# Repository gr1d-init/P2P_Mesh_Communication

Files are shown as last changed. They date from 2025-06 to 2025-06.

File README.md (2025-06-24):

# P2P_Mesh_Communication_Learning_Kit_SKEE1103_C_Programming_for_Engineers

For this project, our main targeted users were particularly the high school students who are able to comprehend most basic peer-to-peer mesh communication knowledge which often included in STEM subject syllabus such as Computer Science and Physics subject. 

Other than that, students are also exposed to an exciting involvement in Arduino kit development, lies under the usage of microcontrollers, which is a foundational skillset for their Reka Bentuk Teknologi subject that includes hardware and software implementations.

In short, we want student to head the ground up, build up a Peer-to-Peer Mesh Communication Device on their own with given instructions manual, enhance their practical skills on utilise a microcontroller and strengthen their understanding towards wireless communication protocols.

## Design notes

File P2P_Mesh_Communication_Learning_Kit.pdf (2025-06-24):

## ACADEMIC SESSION

2024/2025

# SKEE1103

## C PROGRAMMING FOR ENGINEERS

# GROUP PROJECT

## P2P MESH COMMUNICATION LEARNING KIT

## SECTION 02

## LECTURER: DR. NUR FAIZAL BIN KASRI

# PREPARED BY:

NAME | MATRIC NO.
CHIN YUAN YI | A24KE5081
KOK QI SHENG | A24KE0121
LIM ENG CHIEN | A24KE0138
OOI WEY SHEN | A24KE0270
TONG JIA SHEN | A24KE0313

## Team Description

# TrekAlert

Project Director & Hardware Implementation

Kok Qi Sheng

## “Led the team and constructed the hardware system, ensuring all components were properly assembled and fully functional”

Schematic Drawing & Software Simulation

Lim Eng Chien

## “Created the schematic diagrams and implemented software simulations to verify the design prior to physical assembly”

Assembly & Operational Manual

Chin Yuan Yi
Tong Jia Shen

## “Carried out the hardware assembly process and contributed to writing the instructions manual to ensure proper setup and usage for users”

Documentation

Ooi Wey Shen

## “Conducted research towards the theoretical background and prepared a clear documentation for the report”

## Table of Contents

Section and Title | Page
1.0 Introduction | 1, 2
1.1 Problem Statement | 1
1.2 Objectives | 1
1.3 Scope | 1, 2
2.0 Literature Review | 3, 4
2.1 Overview of Decentralised Mesh Communication Technologies | 3, 4
2.2 Justification for nRF24L01+ Kit | 4
3.0 Methodology | 5, 6
3.1 Problem Formulation | 5
3.2 Hardware and Firmware Design | 5
3.3 Instructional Materials | 6
3.4 Testing and Verification | 6
3.5 Iteration | 6
3.6 Limitations and Future Improvements | 6
4.0 System Overview | 7, 8
4.1 Peer-to-Peer and Mesh Communication Principles | 7, 8
4.2 TrekAlert Working Principle | 8
5.0 Hardware Description, Designs and Implementation | 9 - 18
5.1 Processing Unit: Arduino Nano | 9
5.2 Transceiver Module: nRF24L01+ | 10, 11
5.3 Power Supply | 12
5.4 I/O Device | 13 -15
5.4.1 Push Button Configuration (Microcontroller Input) | 13
5.4.2 LED Configuration (Microcontroller Output) | 14
5.5 Designs and Implementation | 16 - 18
5.5.1 Block Diagram | 16
5.5.2 Fritzing Schematic | 16, 17
5.5.3 KiCad PCB Design and 3D Model Rendering | 17, 18
5.5.4 Final Prototype | 18
6.0 Software Description, Designs and Implementation | 19 - 21
6.1 Feature Overview | 21
7.0 Results and Discussion | 22 - 34
7.1 Assembly Instructions | 22 - 29
7.2 Firmware Installation Instructions | 30 - 32
7.3 Operating Instructions | 33, 34
7.4 Result Showcase | 34
8.0 Future Work | 35
9.0 Conclusion | 36

### 10.0 References

37, 38

1

### 1.0 Appendix

3

9

## 1.0 Introduction

For this project, our main targeted users were particularly the high school students who are able to comprehend most basic peer-to-peer mesh communication knowledge which often included in STEM subject syllabus such as Computer Science and Physics subject.

Other than that, students are also exposed to an exciting involvement in Arduino kit development, lies under the usage of microcontrollers, which is a foundational skillset for their Reka Bentuk Teknologi subject that includes hardware and software implementations.

In short, we want student to head the ground up, build up a Peer-to-Peer Mesh Communication Device on their own with given instructions manual, enhance their practical skills on utilise a microcontroller and strengthen their understanding towards wireless communication protocols.

### 1.1 Problem Statement

In rural or low signal areas such as jungle, mountain trails, maritime or disaster zones, the conventional communication device including mobile phones required cellular network which might no longer available in service.

This presents a huge challenge in terms of team coordination and emergency communication. To address this problem, we introduced the product, TrekAlert, equipped with Peer-to-Peer (P2P) Mesh Communication Technology using Radio Frequency (RF) Wireless Communication Protocol.

RF technology is being targeted to outperform other wireless communication protocols such as WiFi, Bluetooth, Cellular Networks, AM/FM in this specific use case. By utilising this technology as P2P transceiver medium, the nodes can communicate between devices without the aid of cellular network.

### 1.2 Objectives

Develop a hands-on learning kit to demonstrate P2P mesh communication principles
The kit simplifies the concepts of peer-to-peer and mesh communication. This allows students to observe how devices transmit and receive messages across the network without a central hub.

Enable students to design, assemble and program a working device
This kit empowers students to go beyond theory by requiring them to assemble hardware components and getting exposed with firmware that controls the communication nodes. The following will provide them practical experiences with basic microcontroller programming and digital electronic system.

Demonstrate safe, warning and emergency signal propagation without relying on cellular networks
The kit simulates real-world scenarios where conventional communication networks may be unavailable. Students can explore how independent nodes share status updates across the network by sending and receiving predefined signal, in this case, SAFE, WARNING and SOS

### 1.3 Scope

This project focuses on the study of mechanism, design, implementation and demonstration of a peer-to-peer (P2P) mesh communication kit with Arduino Nano and nRF24L01+ module. The scope includes:

- Developing hardware and software that enable basic signal transmission (Safe, Warning, SOS) between multiple nodes.
- Providing hands-on assembly instructions, testing procedures and a ready-to-use educational kit.
- Exploring educational aspects, scale down the conventional devices, allowing students to gain practical experience with microcontrollers and wireless communication

This scope ensures the kit is suitable for classroom and beginner use, while laying the groundwork for future enhancements, such as extended range (LoRa, Zigbee) or graphical displays. For more details, refer future works being discussed in the latter section of the report.

## 2.0 Literature Review

In a real-world application, this kit can be used in various scenarios that lack of cellular network and internet. This includes but not limited to jungle trekking, island explorations and maritime rescue.

Peer-to-peer and mesh wireless communication using LoRa, Zigbee and similar radio technologies has been widely adopted in professional and industry sectors among off-grid applications. For example, military use devices like goTenna Pro X [1] to maintain communication without cellular networks during search and rescue operations. Agricultural sectors also deploy LoRa-based mesh networks, specifically LoRaWAN (Low Power Wide Area Network) [2] for remote sensing and automation, such as monitoring soil moisture and water management across large outdoor areas. For more details, see [3].

Despite these established industrial uses, peer-to-peer mesh radio frequency technology remains niche outside specialized domains. Consumer devices rarely feature these protocols and most personal wireless communication still highly depends on cellular, Wi-Fi, or Bluetooth.

### 2.1 Overview of Decentralised Mesh Communication Technologies

Mesh networking allows devices (which are also known as nodes) to communicate with each other directly or indirectly via intermediate nodes. Meanwhile, data are often encrypted with AES-256 encryption method and routed through secure paths among the mesh topology, hence ensure the data integrity when transferring between nodes, prevent intermediate nodes from accessing other nodes’ message transfer process [4]

Traditional Wi-Fi technology also includes mesh solution, however from a topper view, it still relies on central ISP (Internet Service Provider) thus it is categorised under centralised mesh solution. In this subsection, mainly decentralised mesh solution will be discussed, especially Radio Frequency and Bluetooth. Several decentralised mesh communications technologies have been developed for embedded system and IoT applications:

Figure 1: Node in General Mesh Networking. Adapted from [5]

Protocol | Range & Data Rate | Cost & Complexity | Suitability
Zigbee [6] | Short (~10–100 m), moderate data rate | Expensive modules, requires coordinator, complex setup | Common in home automation; too complex for most beginners
LoRa [7] | Long (~10 km), very low data rate | Expensive, low bandwidth, not real-time | Good for long-range, low updates; unsuitable for responsive projects
BLE Mesh [8] | Short (~10–50 m), moderate data rate | Requires significant memory and setup | Large-scale device comms; too advanced

| | | for simple Arduino projects
nRF24L01+ [9] | Short (~10–100 m), moderate data rate | Very low cost, simple to use, low power | Beginner-friendly P2P; can emulate mesh via custom relay or tree-based routing

Table 2

### 2.2 Justification for nRF24L01+ Kit

After careful consideration and analysis, the Arduino + nRF24L01+ is the most ideal solution for this P2P Mesh Communication Educational Kit due to several reasons:
- Low cost
- Scale down a conventional use case of Radio Frequency Technology, rather than using a Bluetooth technology
- Beginner friendly, enable students’ hands-on interaction on both hardware and software for educational purposes
- Energy efficient, only consumes a low power, suitable for TrekAlert which focus as a pocket tool

## 3.0 Methodology

This section describes the systematic approach taken to design, implement and verify the TrekAlert P2P Mesh Communication Learning Kit as a hands-on learning tool for high school students. The methodology integrates educational learning outcomes with a practical engineering design process to ensure the kit is beginner friendly and low learning curve towards technical aspects.

### 3.1 Problem Formulation

The primary objective is to introduce students to RF wireless peer-to-peer (P2P) decentralised mesh communication, a concept often overlooked in traditional STEM curriculum that focus mostly on Wi-Fi, cellular networks or Bluetooth that most of them rely on the central infrastructure.

Hypothetically, if students can successfully build the kit using provided hardware and instruction manual, able to carry out sending and receive messages across a small RF mesh network, then the kit is an effective educational tool for demonstrating decentralised mesh communication.

Educational goals:
- Develop students’ practical experiences in hardware assembly, microcontroller programming and basic wireless communication protocol
- Strengthen understanding towards RF technology, decentralised P2P mesh communication and logic level manipulation in microcontroller programming
- Encourage and inspire students to excavate the field of communication, contribute to the STEM environment

### 3.2 Hardware and Firmware Design

### 3.2.1 Hardware Design

We selected mainly the low-cost, beginner-friendly components so student can afford them:
- Arduino Nano as control board
- nRF24L01+ transceiver for P2P RF messaging
- LEDs to indicate nodes’ status
- Battery powered for a better portability

### 3.2.2 Firmware Development

Firmware was developed through Arduino code and plugged in with RF24 library that simplifies the wireless messaging between nodes by automating acknowledgement and retransmission process.

Each node carries out a cycle on checking message transmission and reception status, communicate using SAFE/WARNING/SOS states. The firmware source code was well commented and named with proper variables that ensure students can grasp the logic easily and make modifications on top of it for further development. The instruction manual maps the hardware stage to the firmware stage in detail so students can clearly see how each part corresponds to the firmware.

### 3.3 Instructional Materials

A step-by-step instruction for assembling the kit and microcontroller operation mode was well illustrated and discussed, that includes:
- Wiring the components by following the graphical steps, according to the Fritzing schematics
- When assembling the components, understand how active low components were hardware-defined, learn the proper method to setup for different configuration modes
- Installing the firmware source code from GitHub
- Verify and upload firmware to node’s microcontroller chip

### 3.4 Testing and Verification

With two nodes powered on at short range (~15m), students:
- Sent and received predefined messages between the two nodes
- Confirmed successful transceive capability and bidirectional communication
- Verified that communication was achieved without the aid of cellular networks or internet
- Verified nodes’ P2P decentralised mesh communication capability

With the open-source access provided through GitHub, students may always revise the Learning Kit details and modify its usage, carry out further study on theoretical concepts such as radio frequency technology and P2P networks independently.

### 3.5 Iteration

The educators can always visit our project repository, follow the same implementation methodology, they could provide the educational session with their target users, not limited to students only. Researchers or hobbyists can also access the whole project report, to support their own case study or self-guided learning.

### 3.6 Limitations and Future Improvements

While this version only support demonstration for basic two nodes communication, future enhancements may include:
- Adding more nodes to showcase mesh network’s relay capabilities
- Expand to a longer ranged RF network using LoRa technology
- Integrating GUI display for more interactive STEM educational demonstration

For more details on future enhancements, refer 8.0 Future Work section.

## 4.0 System Overview

### 4.1 Peer-to-Peer and Mesh Communication Principles

Each node in the network can function as both a transmitter and a receiver in the independent communication model and that refers to peer-to-peer (P2P) communication. P2P systems improve reliability and autonomy by getting rid with the need for a central infrastructure, in contrast to conventional client-server architectures. In simple word, every node is the central hub itself.

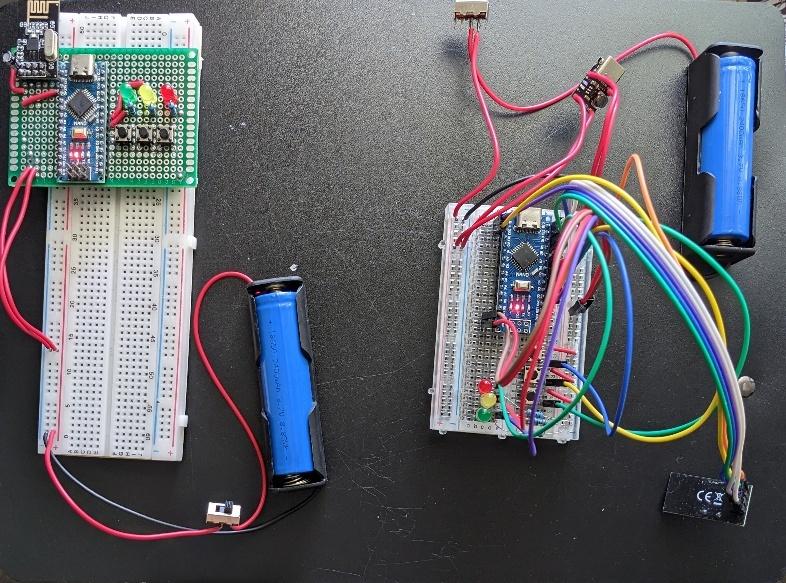
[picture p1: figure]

Figure 2: Two isolated node communication devices

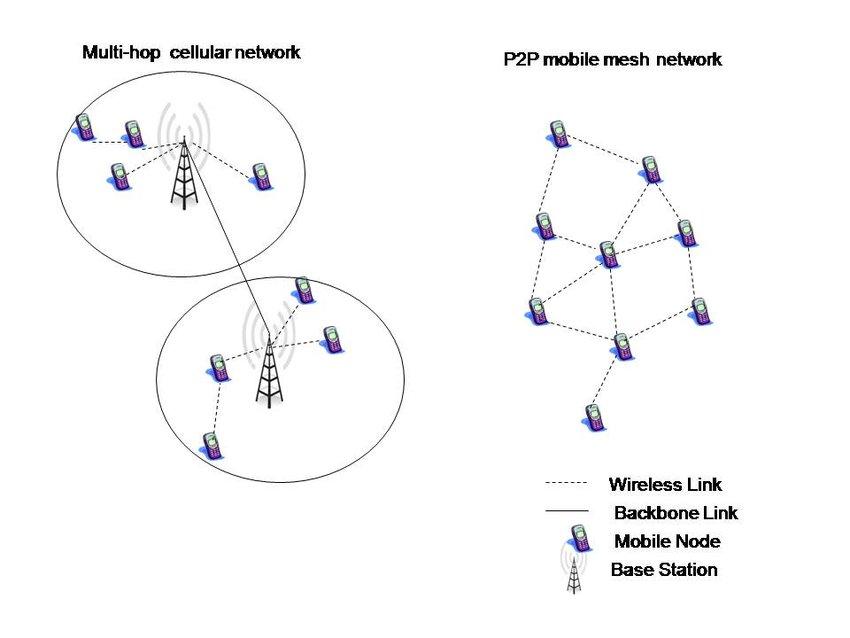
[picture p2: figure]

Figure 3: Comparison between traditional cellular network and P2P decentralised mesh network Adapted from [10]

The P2P idea is extended by mesh communication, which enables several nodes to transmit messages through one another in addition to communicating directly. As a result, data can travel via a variety of routes to reach its destination, forming a decentralised network, enhancing:
- Reliability: Alternative routes can be used if one node fails.
- Scalability: The network can dynamically add new nodes as needed.
- Coverage: Intermediate nodes allow signal coverage to expand wider, act as a signal repeater

Mesh networking can be divided into two categories:
Full Mesh | Partial Mesh (Ad Hoc) [11]

This is the best option, but it requires a lot of work and resources because every node is directly connected to every other node.

This kit uses nodes that connect directly or indirectly, dependent on signal strength or distance. This technology is used by TrekAlert Table 3, Mesh Network Topology, Diagrams adapted from [12]

### 4.2 TrekAlert Working Principle

The TrekAlert Communication System is a portable rechargeable battery-operated Arduino-based device that allows peer-to-peer (P2P) decentralised mesh communication. It enables users to use push buttons to transceive the three predefined status signals—Safe, Warning and SOS from a node to another without cellular network.

The nRF24L01+ module at first node is used to wirelessly broadcast the signals, which are then routed throughout the mesh network and represented on second transceiver nodes by color-coded LEDs. On the other hand, the functionality as transmitter and receiver can be swapped between nodes, allowing a bidirectional communication, which make it outperform the traditional AM/FM transmission and reception.

This kit enables a group of users to communicate basic safety statuses through wireless signal propagation using the nRF24L01+ transceiver module in mesh networks, which every node act as the central device itself.

Each node in the system is an independent device that can carry out three major functions, which are:
- Sending status signals via push button, act as transmitter
- Receiving signals from other nodes, act as receiver
- Communicate with each other bidirectionally through various colours of LEDs with real-time operation, act as transceiver

Three predefined signals can be transmitted by triggering the respective push button through this kit (Table 1):
No. | LED | Message
1 | Green | SAFE (Clear)
2 | Yellow | WARNING (Caution)
3 | Red | SOS (Emergency)
Table 1

## 5.0 Hardware Description, Designs and Implementation

For hardware integration, we have dissected into a few operational parts, mainly:
- Processing Unit
- RF Transceiver
- I/O Device
- Power Supply

### 5.1 Processing Unit: Arduino Nano

The central processing unit (CPU) in each TrekAlert node is the Arduino Nano. It controls push button input detection, RF wireless communication with nRF24l01+ via SPI Protocol and LED signalling. Arduino Nano is best suited for TrekAlert because of its small size, as compared to Arduino UNO, its USB-C programmability, low power consumption and sufficient amount of digital I/O pins makes it an ideal choice for this project.

Figure 4: Arduino Nano. Adapted from [13]

Arduino Nano is based on ATMega328P 8-bit AVR microprocessor. It runs with a clock speed of 16 MHz and operates at a controlled 5 V in this case. Arduino Nano equipped with 14 digital input/output (I/O) pins (D0 – D13) and 8 analog input pins (A0 – A7). It also supports communication between nRF24L01+ module via SPI hardware protocol

Main function of microcontroller in Trek:
- Input Monitoring
Each push button is wired with a pull-up resistor so that the corresponding Nano input pin stays HIGH by default. When a button is pressed, the input pin goes LOW, signalling the microcontroller to begin processing.
- Signal Encoding
When a button is pressed, the Nano encodes a message to SPI protocol, containing:
- The signal type (which button was pressed)
- The node ID (which device is sending)
- A message ID (to help prevent duplicates)
- Data Transmission and Reception
Neighbouring nodes receive the transmitted message through their nRF24L01+ modules over SPI protocol. Each node checks if the message is new, then processes the signal, e.g. triggering a button causes another node to light up an LED.

### 5.2 Transceiver Module: nRF24L01+

The nRF24L01+ is a popular wireless transceiver module that enables communication between microcontrollers. The compact and energy-efficient characteristics, making it easily integrated into educational and embedded projects that required RF wireless communication. Its firmware provided features like automated handshaking and retransmission [14], hence making its setup easier and beginner friendly. Moreover, there are also versions with enhanced antennas available in the market, providing an extended range and stability option for more demanding usages. [15]

Figure 5: nRF24L01+

The following are the key specifications of the nRF24L01+:

Feature | Description
Frequency Band | 2.4 GHz ISM
Data Rate | Up to 2 Mbps
Transmission Range | 50–100 m (open space), varies with environment
Communication Protocol | SPI (Serial Peripheral Interface)
Acknowledgment Support | Auto-ACK and Auto Retransmit
Data Pipes | 6 simultaneous data pipes
Payload Size | Up to 32 bytes per message
External Antenna Option | Available for increased range and reliability
Power Consumption | Very low, ideal for battery-powered devices
Common Applications | Educational kits, embedded systems, P2P or mesh-like networks

Table 4: nRF24L01+ specifications. For more details, see [16].

SPI (Serial Peripheral Interface) and Its Role

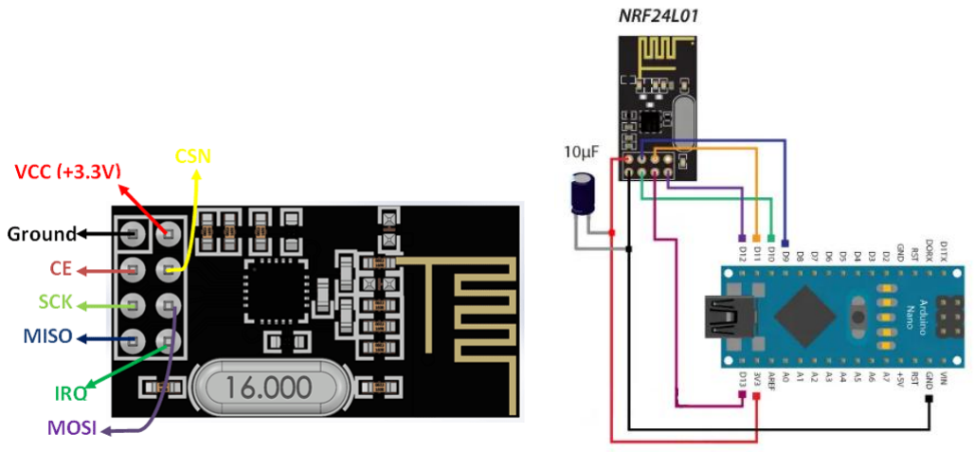
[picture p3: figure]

Figure 6: nRF24L01+ Pinout. Adapted from [9]

The Arduino Nano, a microcontroller act as a Master device and the nRF24L01+ wireless module, a peripheral act as a Slave device can exchange data via the Serial Peripheral Interface (SPI) and it supports the core functionality for TrekAlert, as it is a full-duplex comfmunication protocol.

Pin | Full Name | Direction | Description
MOSI | Master Out, Slave In | Master → Slave | Sends command bytes and data from the microcontroller to the nRF24L01+
MISO | Master In, Slave Out | Slave → Master | Sends data from the nRF24L01+ back to the microcontroller
SCK | Serial Clock | Master → Slave | Synchronizes data transmission
CSN | Chip Select Not | Active Low | Enables (LOW) or disables (HIGH) communication
CE | Chip Enable | Active High | Enables the transceiver to transmit or receive data

Table 5: nRF24L01+ pinout details (SPI Interfrace). Adapted from [17]

### 1. Initialisation

When the system is powered on:
- The Arduino initialises the nRF24L01+ by writing values to its internal configuration registers over SPI.
- This setup includes:
- Payload size
- Transmission power level
- Communication channel (frequency)
- CRC (Cyclic Redundancy Check) error validation and automated acknowledgement

### 2. Transmission

- The Arduino generates the data packet and writes it into the nRF24L01+’s TX FIFO buffer using the SPI protocol.
- The CE (Chip Enable) pin is briefly pulled HIGH to begin transmitting after the data is loaded.
- The signal is subsequently transmitted by the NRF module using 2.4 GHz radio waves.

### 3. Reception

- On the receiving node, the nRF24L01+ listens in RX mode and sets an interrupt flag upon receiving a valid packet.
- The Arduino then reads the data from the RX FIFO buffer using SPI commands.
- After decoding the message, the microcontroller initiates the relevant output action (e.g. turning on the LED to indicate the message).
4. Role of CSN
- The CSN pin is pulled LOW to start SPI communication and HIGH to stop it.
- This guarantees that only one device is active on the SPI bus at a time.

### 5.3 Power Supply

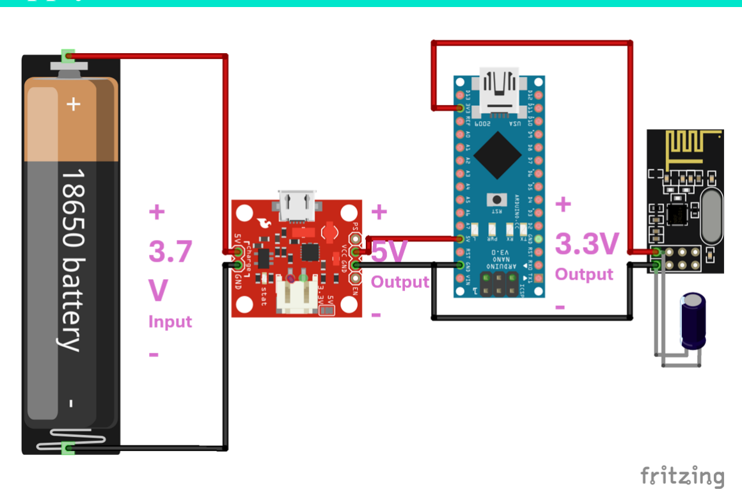
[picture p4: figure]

Figure 7: Power Supply Setup

In our TrekAlert P2P Mesh Communication, we use a charger/booster module to drive the microcontroller and the nRF24L01+ module. Power is supplied by a single 18650 3.7 V Li-ion battery, which is connected into the charger module. The charger module then provides a regulated 5 V output that is fed into the 5V and GND pins of the Arduino Nano.

Meanwhile, the nRF24L01+ module takes its 3.3 V input from the 3V3 output pin on the Arduino Nano. An additional decoupling capacitor is added across the positive and negative terminal to act as a filter, filtering the noise from entering as input.

The charger module also provides a rechargeable solution, allowing battery to be charged without removing it from the enclosure. In off-grid situations such as jungle-trekking, this feature extends the usage time of the device when paired with a power bank, avoid unnecessary battery swaps.

### 5.4 I/O Device

### 5.4.1 Push Button Configuration (Microcontroller Input)

In this project, tactile push buttons are used as the inputs for the user to control the input signals. To ensure a logic level stability when the button is left unpressed, pull-up or pull-down resistors are needed to avoid the floating input.

- Pull-up resistor: Connects the input GPIO pin to Vcc through the resistor. Default state is pulled to HIGH, pressing the button pulls it LOW.
- Pull-down resistor: Connects the input GPIO pin to Ground through the resistor. Default state is pulled LOW, pressing the button pulls it HIGH.
Pull-up resistor | Pull-down resistor

Figure 8: Pull-up and pull-down resistor configurations. Adapted from [18].

Additionally, the resistance value of R1 is crucial for ensuring a stable pull-up or pull-down configuration:

- If R1 is too small, a large current will flow when the switch is closed, resulting an unnecessary power loses. This is known as using a strong pull-up (or pull-down) and less power efficient.
- If R1 is too large, the input may fail to reach a valid logic level when the switch is open due to leakage currents at the microcontroller’s pin. This is referred to as using a weak pull-up (or pull-down).

In TrekAlert, an INTERNAL PULLUP configuration is used to ensure a HIGH logic level by default when button is not pressed. This design results in an active-low configuration, where pressing a button applies a LOW signal to the microcontroller’s input pin. Internal pullup applied the pull-up resistor concept but without the need of adding an external resistor, as built-in microcontroller’s internal pull-up resistor is used.

Configuration wise, common recommendation for external pull-up or pull-down configuration is to select a resistor that is at least 10 times smaller than the impedance of the input pin.

By understanding the principles of circuit behaviour in the circuit, students can understand the voltage divider behaviour. Besides, students can explore logic design and the importance of state management in embedded systems.

### 5.4.2 LED Configuration (Microcontroller Output)

Light-emitting diodes (LEDs) are used in this educational kit as visual indicators for the three statuses, “SAFE, WARNING, SOS”. For a complete tutorial towards LEDs operation, this educational includes the explanation for both active-high and active-low configuration for LEDs. However, the final prototype for this educational kit is equipped with active-low configuration only.

- Active-high: The LED turns ON when the LED’s pin receives a HIGH logic level output by control pin
- Active-low: The LED turns ON when the LED’s pin receives a LOW logic level output by control pin

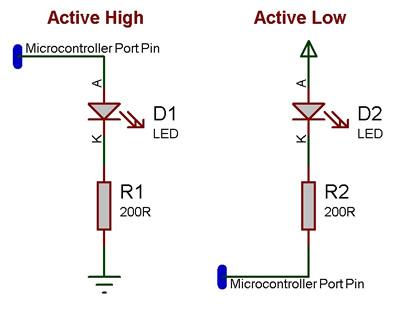
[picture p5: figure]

Figure 9: LEDs’ configuration types. Adapted from [19]

TrekAlert uses an active-low design, meaning that when the microcontroller wants to turn the LED on, it requires GPIO pin to output a LOW signal. In this setup, the cathode of the LED is connected to the microcontroller’s digital output pin through a current-limiting resistor, while the anode is connected to a steady 5 V supply.

When the microcontroller sets its output pin to LOW, it creates a potential difference. This allows current to flow from the 5 V source, through the LED and resistor and into the microcontroller pin. The resulting current flow causes the LED to light up.

In this configuration, the microcontroller is sinking current, which is often more stable and efficient than sourcing current. Thus, the LED illuminates whenever the microcontroller GPIO pin output LOW signal.

The dual-configuration designs of the LED interface enable students to learn:
- How logic levels affect circuit behaviour
- Understand mode of operation of components only defined by hardware
- Reinforce understanding of potential difference, current flow

Signal Flowchart: End-to-End Operation between TrekAlert Node

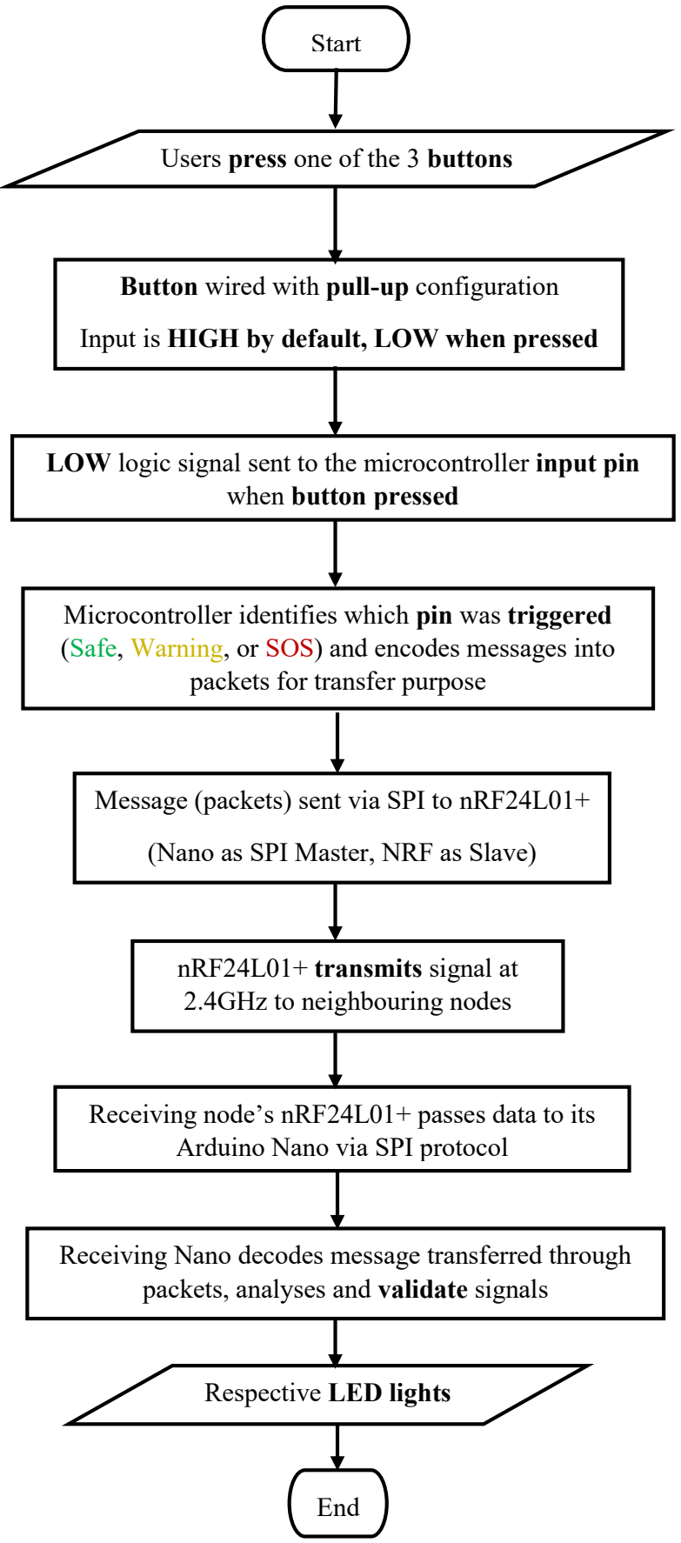
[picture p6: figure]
Start; Button wired with pull-up configuration; when button pressed; packets for transfer purpose; (Nano as SPI Master, NRF as Slave); nRF24L01+ transmits signal at 2.4GHz to neighbouring nodes; Arduino Nano via SPI protocol; packets, analyses and validate signals; Respective LED lights; Users press one of the 3 buttons; End

Input is HIGH by default, LOW when pressed

LOW logic signal sent to the microcontroller input pin

Microcontroller identifies which pin was triggered (Safe, Warning, or SOS) and encodes messages into

Message (packets) sent via SPI to nRF24L01+

Receiving node’s nRF24L01+ passes data to its

Receiving Nano decodes message transferred through

### 5.5 Designs and Implementations

Here comes the section that outlines all the overall system design, circuitry and physical implementation of the TrekAlert project. Several design schematics are provided to illustrate the architecture, interconnections between the components for a final assembly.

### 5.5.1 Block Diagram

Presents a top-level overview of the system, showing the project initiation starting from constructing power supply flow, core components (Arduino Nano, charger module, NRF24L01+) and input/output devices (buttons and LEDs), without the detailed wiring schematics.

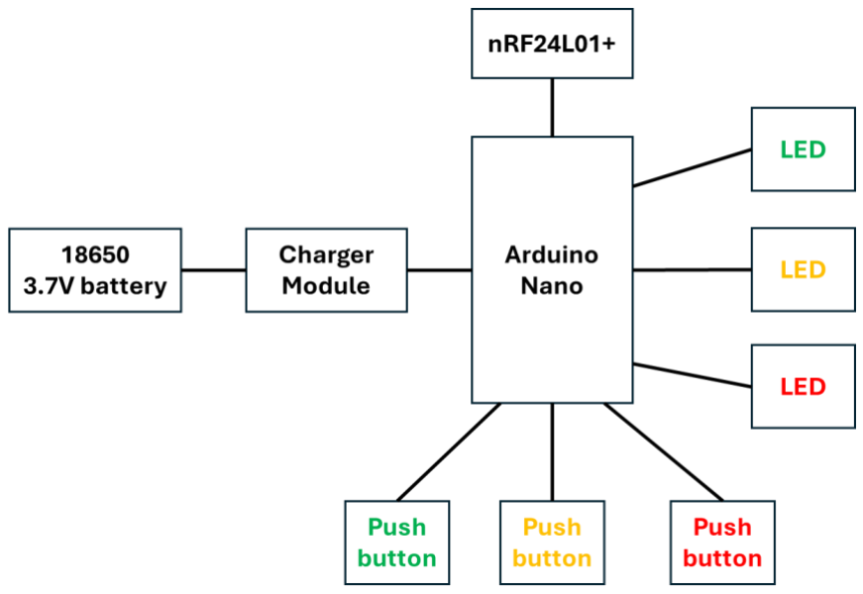
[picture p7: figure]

Figure 10: Block Diagram

### 5.5.2 Fritzing Schematic

Presents a circuit-level wiring of all components on a breadboard, as well as detailed wiring schematics, upgraded from block diagram.

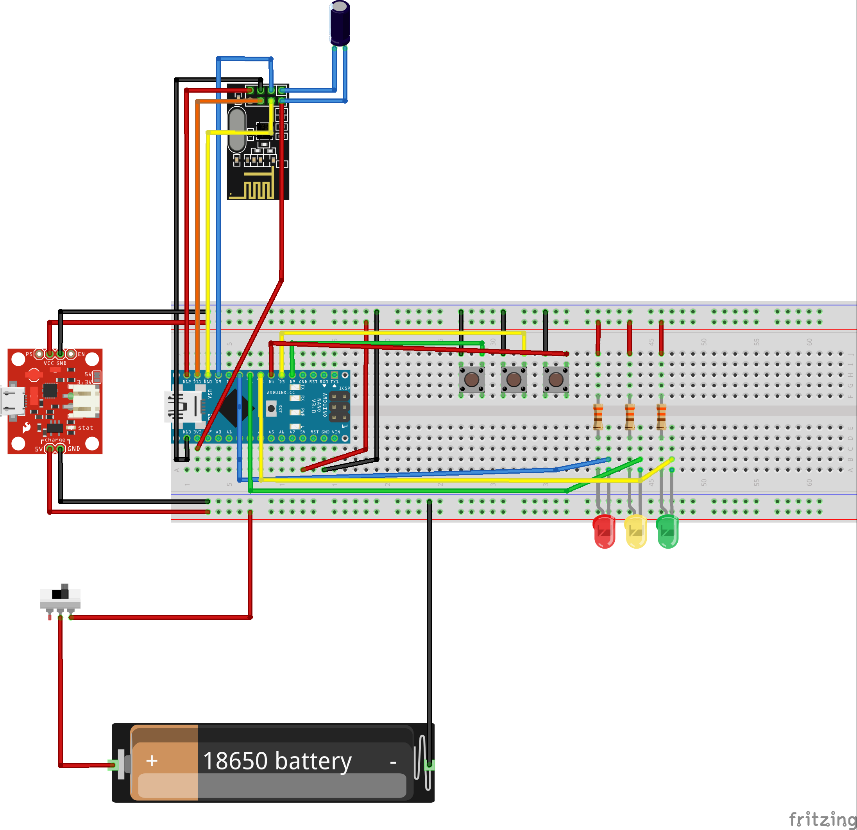
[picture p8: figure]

Figure 11: Breadboard Schematic

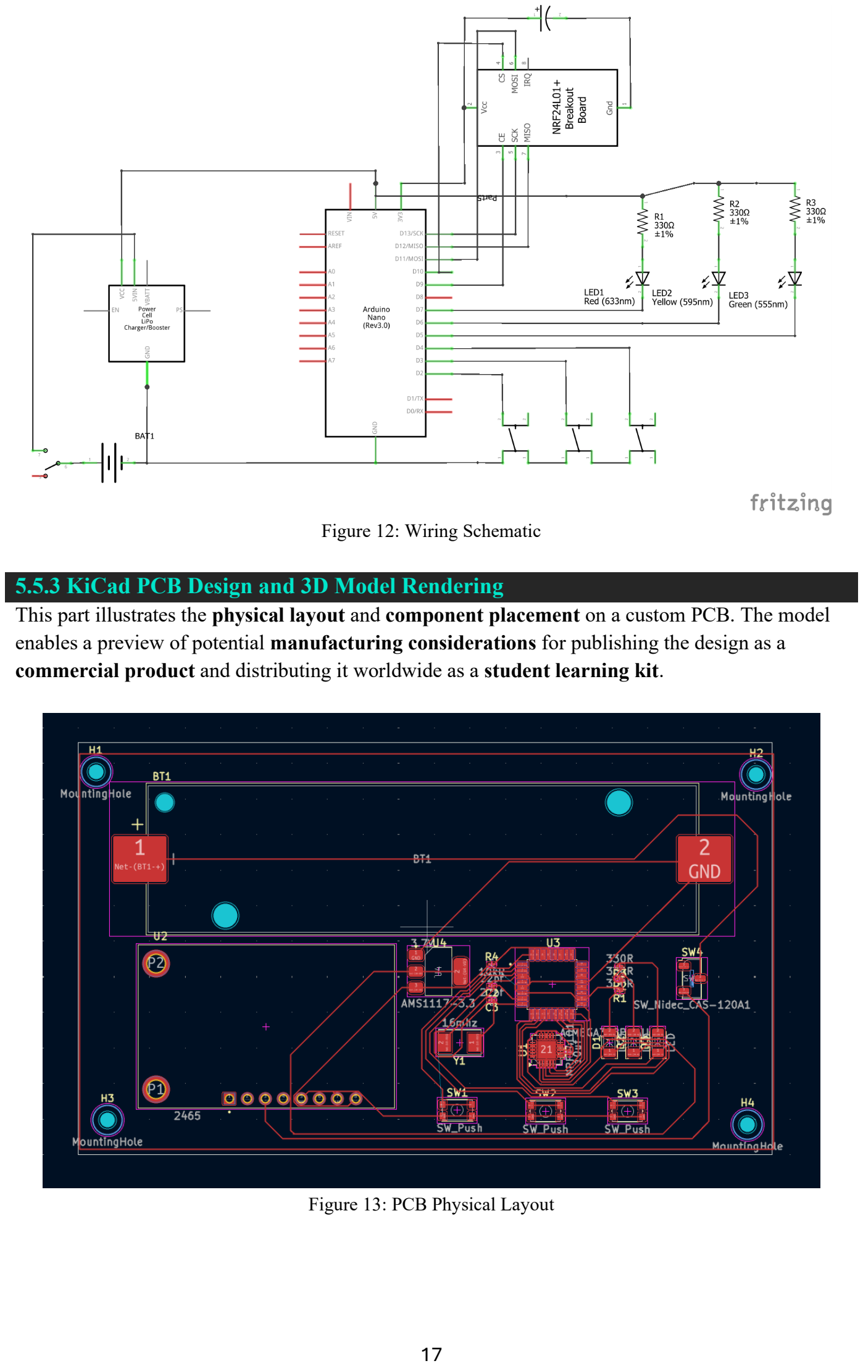
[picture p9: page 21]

Figure 12: Wiring Schematic

### 5.5.3 KiCad PCB Design and 3D Model Rendering

This part illustrates the physical layout and component placement on a custom PCB. The model enables a preview of potential manufacturing considerations for publishing the design as a commercial product and distributing it worldwide as a student learning kit.

Figure 13: PCB Physical Layout

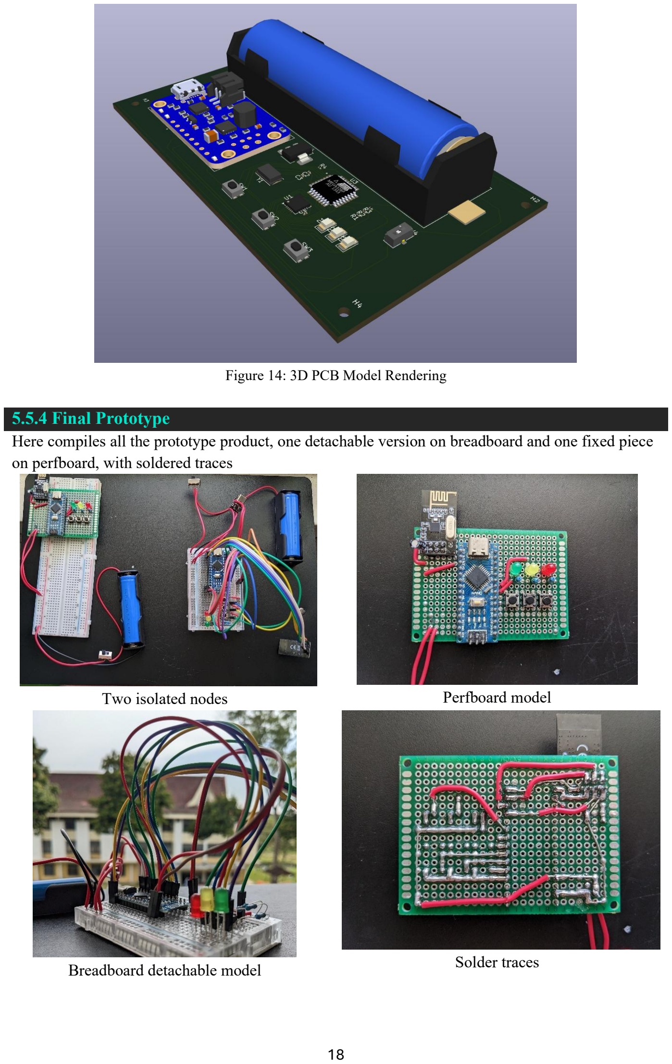
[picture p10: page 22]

Figure 14: 3D PCB Model Rendering

### 5.5.4 Final Prototype

Here compiles all the prototype product, one detachable version on breadboard and one fixed piece on perfboard, with soldered traces

Two isolated nodes | Perfboard model
Breadboard detachable model | Solder traces

## 6.0 Software Description, Designs and Implementations

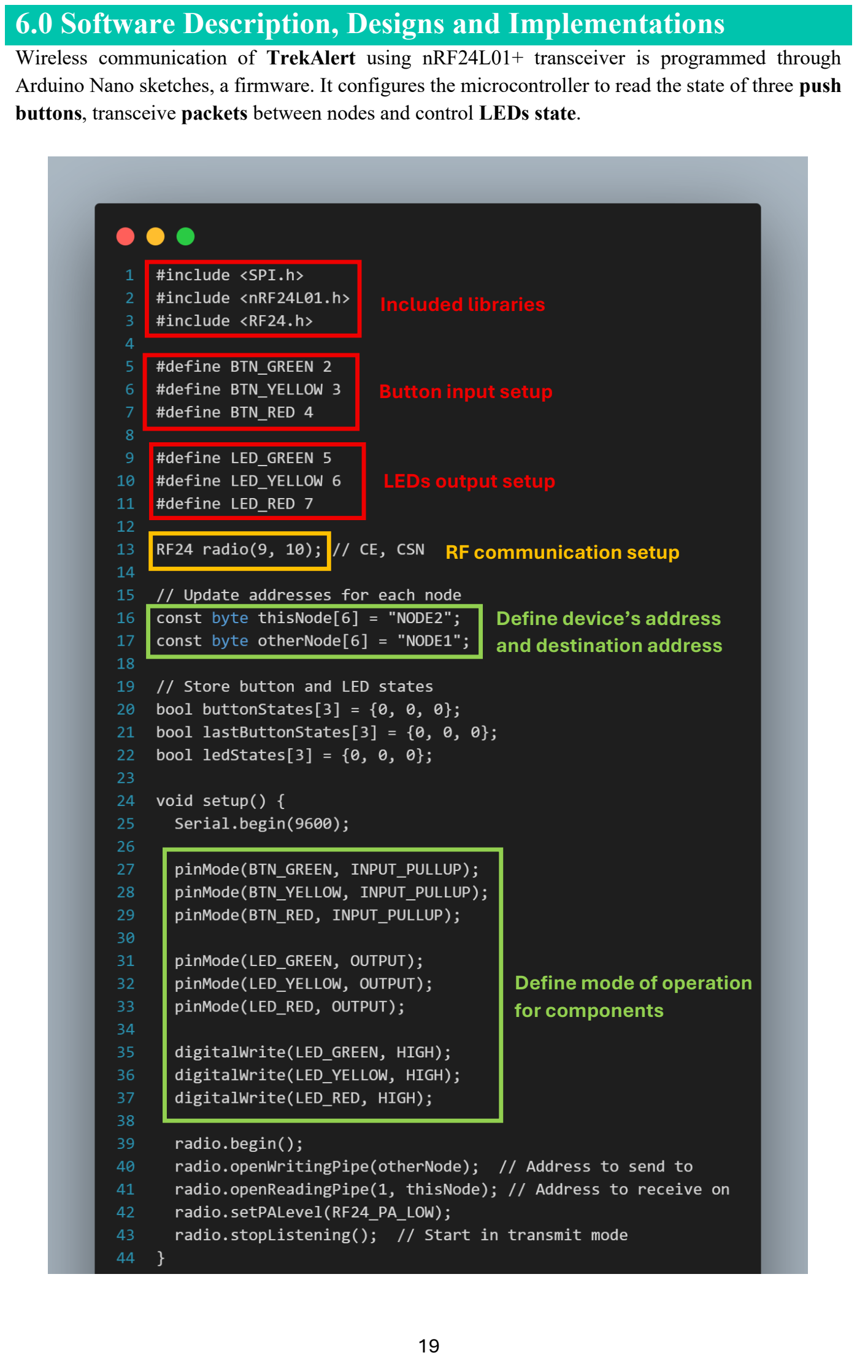
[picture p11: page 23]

Wireless communication of TrekAlert using nRF24L01+ transceiver is programmed through Arduino Nano sketches, a firmware. It configures the microcontroller to read the state of three push buttons, transceive packets between nodes and control LEDs state.

## Included libraries

## Button input setup

## LEDs output setup

## RF communication setup

## Define device’s address and destination address

## Define mode of operation for components

Main loop() logic:
1. Reads the buttons (active-low) and updates the buttonStates
2. Compares current state vs. last state — if any button changed, prepares data to send
3. Uses radio.stopListening(), change to transmit mode, then radio.write() to send updated buttonStates
4. Switches back to receive mode (radio.startListening()), waits for data for up to 5 ms
5. If data is received (radio.available()), updates the LED states

This mechanism flows indicates a construction of transceiver mode for each node. It continuously performs checking and switching between transmitter and receiver modes to ensure the transceiver mode go smoothly.

### 6.1 Feature Highlights

- Edge-triggered Transmission — Only sends new data when a button state changes
- Active-low Input Logic — Uses pull-ups so unpressed buttons read HIGH
- Wireless Duplex — Operates as both transmitter and receiver on the same device with a 5ms checking intervals
- Power Efficiency — Low-power mode for the nRF24L01+ (setPALevel(RF24_PA_LOW))

This firmware integrates hardware inputs (buttons) and outputs (LEDs) with radio communication. Each node continuously monitors its own inputs and broadcasts any changes. It also listens for incoming packets to control its LEDs according to the states sent by its peer.

## 7.0 Results and Discussion

We packaged this P2P Mesh Communication system as a discrete components kit for educational purposes, allowing students to build their own communication device from the ground up.

To support this hands-on learning experience, we have published a detailed instruction manual that includes step-by-step assembly guidelines and demonstrations of its operation.
The demonstration verified that:
- Transceiving process successfully carried out between nodes
- LEDs light up as expected
- System works at certain range

When the user receives this educational kit, there will be 2 modules, one is the perfboard module and the another is a breadboard module, for educational purpose, user will be required to assemble the breadboard module themselves.

Throughout the instructions manual below, students will be able to comprehend the basic mechanism of the device as per discussed

### 7.1 Assembly Instructions

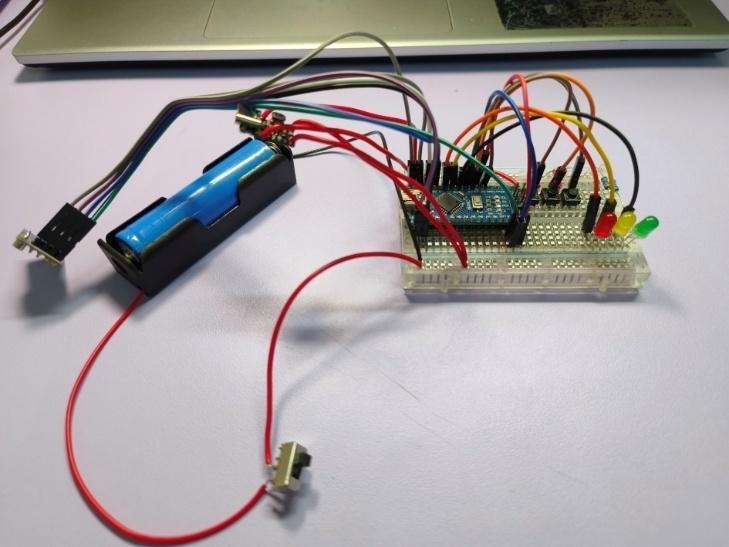
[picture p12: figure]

This Arduino breadboard circuit is a jungle trekking peer-to-peer mesh communication system. By using an nRF24L01+ module, it allows communication between two jungle trekking peer-to-peer devices. Both devices are allowed to send and receive data and trigger the LED on the opposite device, giving simple warnings or alerts to your partner during jungle trekking. It is a great beginner project for students to assemble the device from scratch and learn Arduino with the following components.

Components required

Components | Quantity
Breadboard | 1
Arduino nano board | 1
nRF24L01+ | 1
Charger module | 1
330Ω resistor | 3
Red LED | 1
Yellow LED | 1
Green LED | 1
Push button | 3
Slide switch | 1
3.7V battery | 1
Battery holder | 1
Jumper wires (male to male) | 8
Jumper wires (male to female) | 7

Step 1: Arduino nano
- Place the Arduino nano at the breadboard as show in figure above

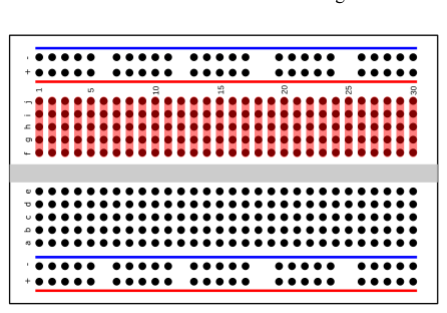
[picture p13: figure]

- The figure above shows the connection in a breadboard
- In the main area, there are 5 holes in each vertical row that are electrically connected. (e.g. a,b,c,d,e holes are connected vertically)
- Horizontal connection in the power rails to connect power and ground across the length of the power rail
- The central gap to keeps the two halves of the main area separated

Step 2: Battery

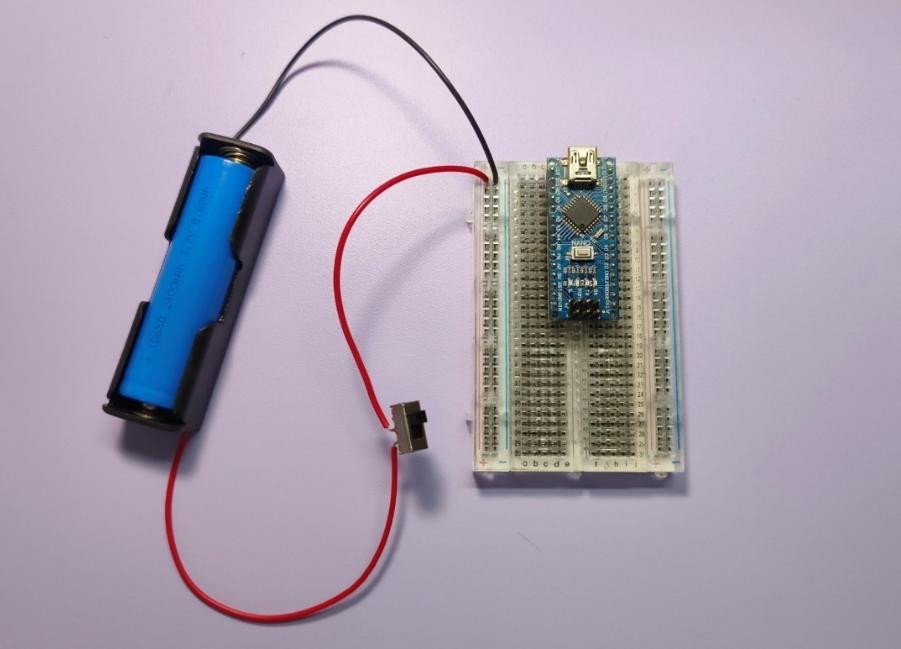
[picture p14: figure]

- Connect the battery to the breadboard as shown in figure above to match with the sign on the breadboard
- Connect the red wire (positive terminal) of the battery holder to breadboard power rail marked ‘+’
- Connect the black wire (negative terminal) of the battery holder to breadboard power rail marked ‘-’
Step 3: Connecting to charger module

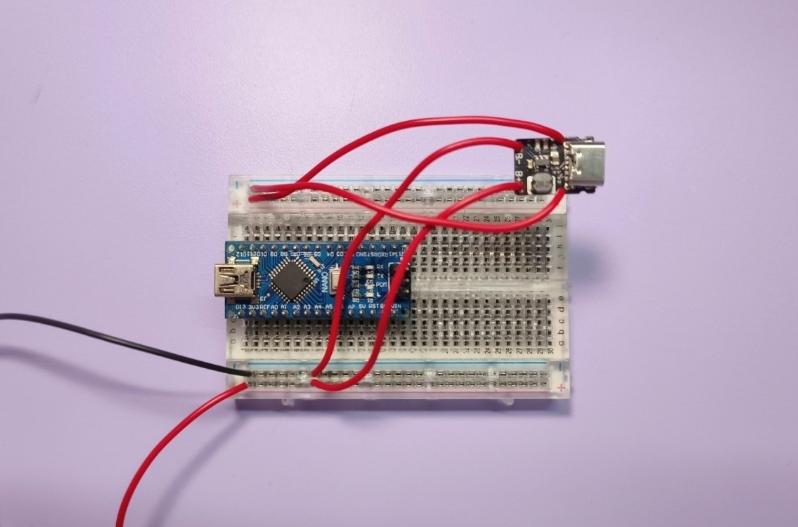
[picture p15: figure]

- The charger module functions as a boost converter, by stepping up 3.7V from the battery to 5.0V, to powering the Arduino nano since it requires 5V input voltage.
- It is also used to charge up the battery with type-c port
- Connect the Charger module to the breadboard as above

- Connect the B+ pin of the charger module to the left + power rail (where the positive terminal of the battery holder is connected)
- Connect the B- pin of the charger module to the left - power rail (where the negative terminal of the battery holder is connected).
•
- Connect the + output pin of the charger module to the right + power rail."
- Connect the - output pin of the charger module to the right - power rail
Step 4: Connect the push button
- The configuration of push button used is active low configuration, meaning the input pin will read low when the button is pressed.
- This setup assume that Arduino nano internal pull-up resistor is used on the input pin.
- Place one push button onto the breadboard, as shown in the figure above
- Connect one terminal of push button to Arduino nano Pin D2
- Connect the other terminal of push button to power rail GND

Repeat this step by connecting 2 more push button

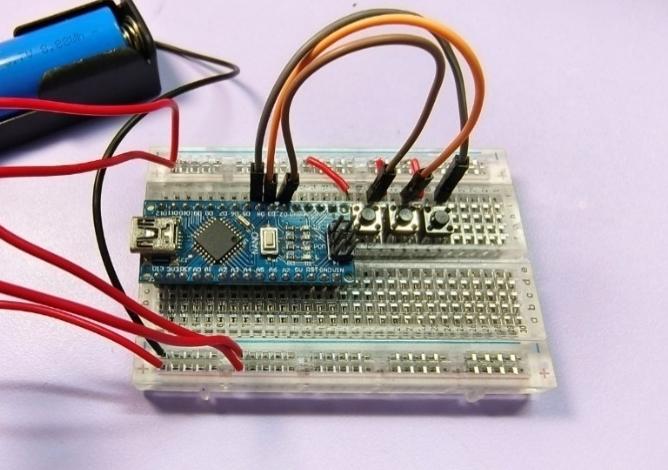
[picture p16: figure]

- Place the push buttons as the setup shown above
- Connecting one terminal of the push button to input pins (D3 and D4) and the other end to GND rail

Step 5: Connecting the LEDs

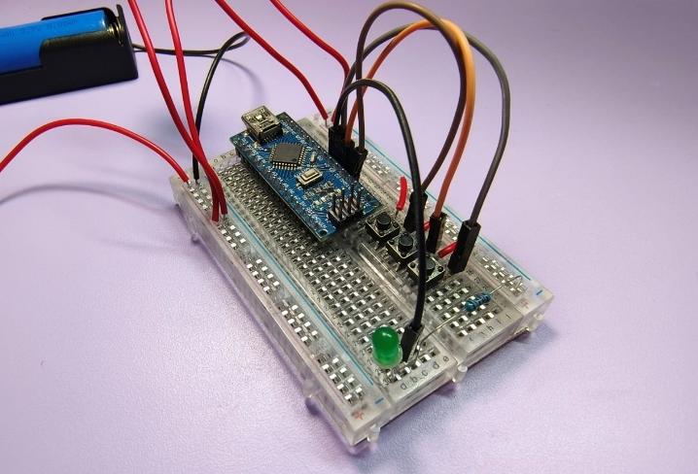
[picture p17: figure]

- The LED is connected in active low configuration
- LED will illuminate when its corresponding GPIO pin (D5,D6,D7) is set to low (0V)
- NOTE: The longer leg of an LED is the anode(+), while the shorter leg of an LED is cathode (-)
- Connect one end of the 330Ω resistor to ‘+’ 5V power rail
- Connect the other end of 330Ω resistor to anode (positive leg) of the LED
- Connect the cathode (negative leg) of LED to the GPIO pin (D7,D6,D5)
- Repeat these steps for the remaining two LEDs (yellow and green), connecting each to a separate GPIO pin (Red to D7, Yellow to D6, Green to D5) as illustrated in the diagram below

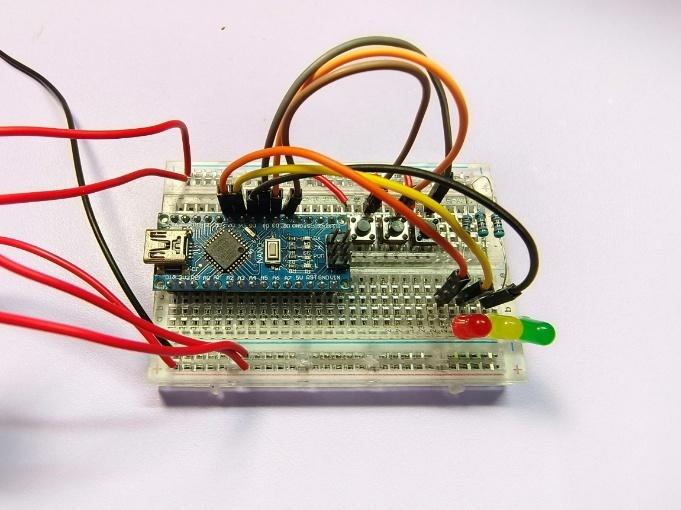
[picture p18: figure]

Step 6: nRF24L01+ module

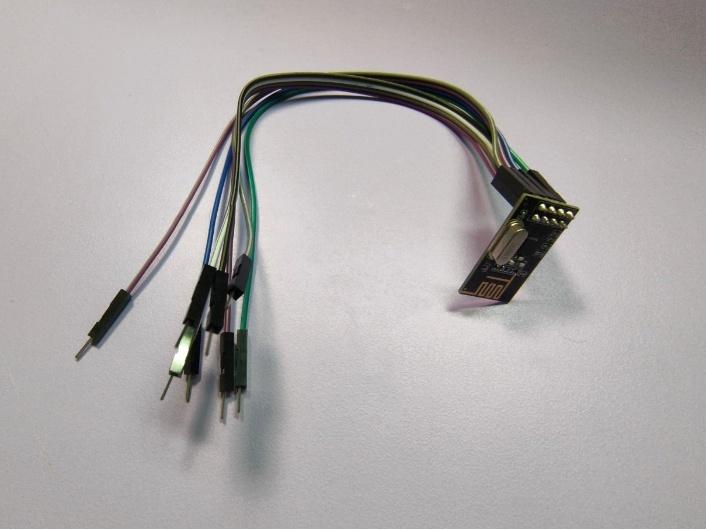
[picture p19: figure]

- Use male to female jumper wire to connect the nRF module to Arduino
- The pinout diagram of nRF module is as below

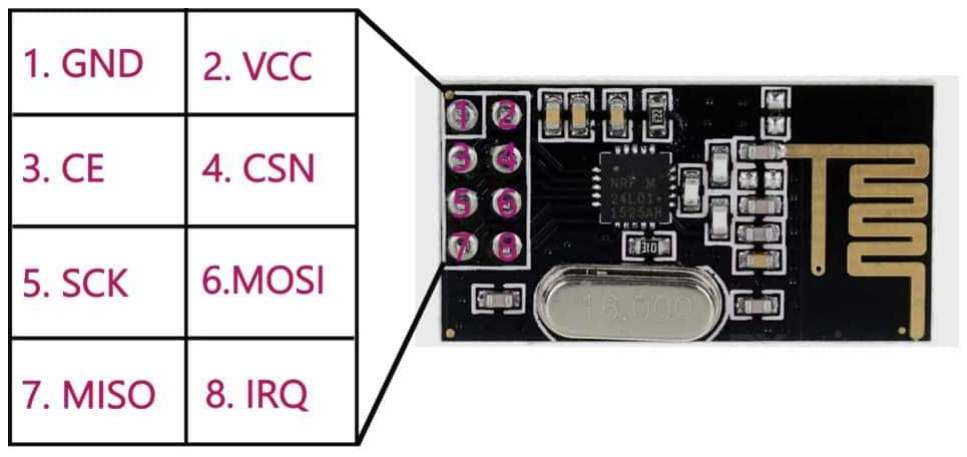
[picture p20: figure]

nRF24L01+ pin | Arduino nano pin
GND | Power rail GND
VCC | Power rail 3.3V (Do not connect to 5V)
CE | D9
CSN | D10
SCK | D13
MOSI | D11
MISO | D12
IRQ | Not used

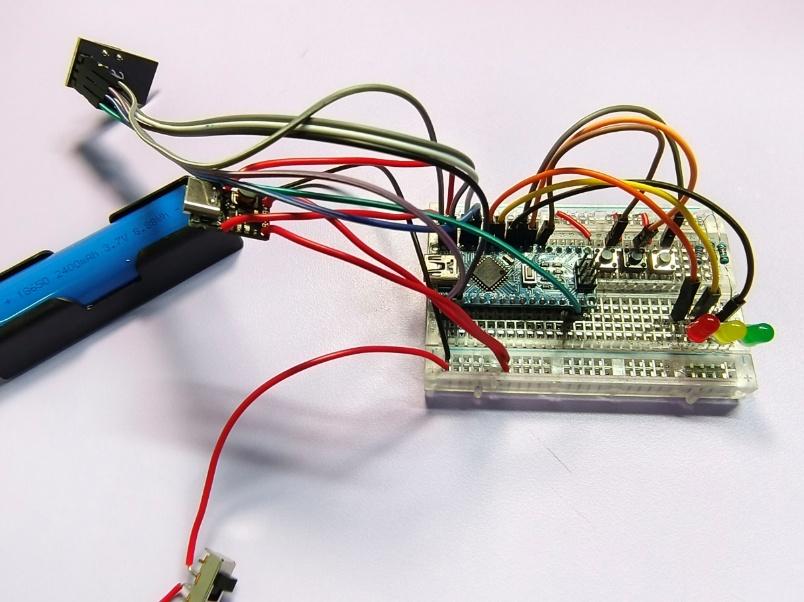
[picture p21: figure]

Step 7: VCC and GND

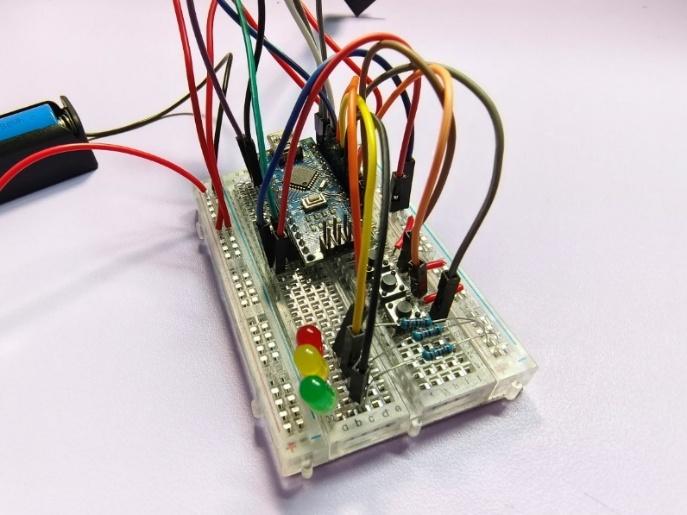
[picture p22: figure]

- Supply power to the Arduino nano from the breadboard regulated 5V and GND power rail
- Connect the Vin pin on the Arduino nano to the ‘+’ (5V) power rail.
- Connect the GND pin on the Arduino nano to the ‘-’ (GND) power rail.

Final product of a single P2P mesh communication node on breadboard

## 7.2 Firmware Installation Instructions

### Step 1: Connect Arduino and PC using cable

Insert the cable type C side to Arduino and USB A side to PC

### Step 2: Configure Arduino Firmware Through Sketches

1) Import Code

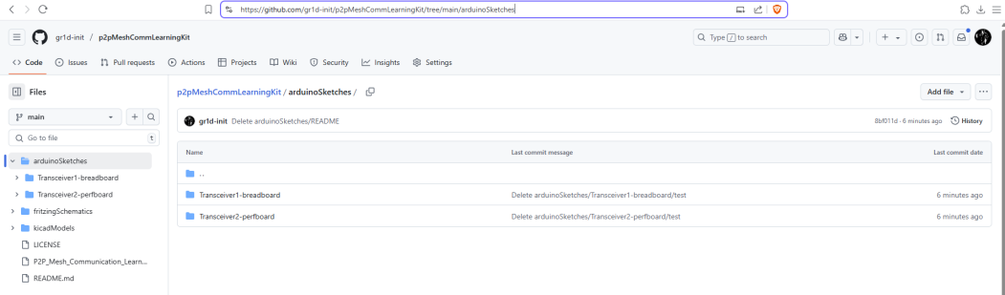
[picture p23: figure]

This project is published to the open-source community on GitHub,
hence students are only required to obtain the firmware from the link below https://github.com/gr1d-init/p2pMeshCommLearningKit/tree/main/arduinoSketches follow the to install the source code, unzip the file and you will get source code file named Transceiver1-breadboard.ino, open it using Arduino IDE
2) Connect Arduino to PC and Initializing

Connect Arduino to your PC using the cable provided, at the top right select the USB port NOTE: If occur more than 1 unknown usb devices, make sure to remove other USB devices on your computer and indicate the USB port name of your Arduino (In this case Arduino are connected to COM6 port)

Now, select Arduino Nano as the board and select the proper port. Click OK to save.

### Step 3: Declaring Coding based on Arduino I/O Pins

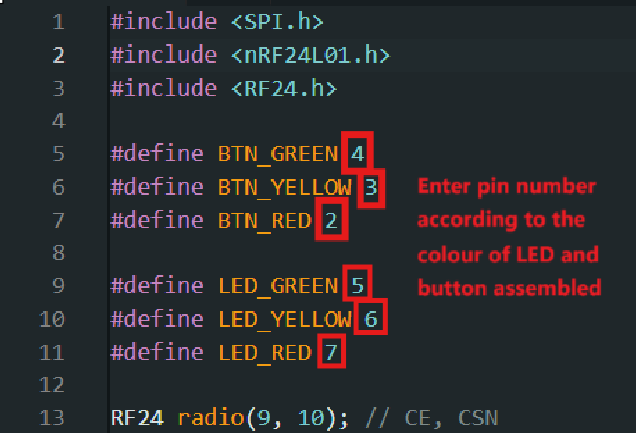
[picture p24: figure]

Now we are focusing on the coding.
From line 5 to line 11, declare the Arduino pin number according to the button and LED assembled.

In this case :

D2 → Blue Jumper → BTN_RED
D3 → Yellow Jumper → BTN_YELLOW D4 → Brown Jumper → BTN_GREEN D5 → Purple Jumper → LED_GREEN D6 → Red Jumper → LED_YELLOW
D7 → Green Jumper → LED_RED

From line 13, declare the Arduino pins according to NRF module.

In this case :
D9 → Green Jumper → CE
D10 → Blue Jumper → CSN

### Step 4: Verify and Upload to Arduino

After done all the declaration, what we need is to burn the firmware into Arduino. The first step is clicking the √ button to verify, waiting IDE to done compiling. Next, click → button to upload the firmware.

Please wait patiently and DO NOT disconnect the Arduino from your PC while uploading.

At the end, you are successfully burned in the firmware once the Done Uploading message pop up.

## 7.3 Operating Instructions

### Step 1: Turn on Power Supply

Push the button
to ON 1

The power indicator
light will turn on

indicate Arduino are 2 in working mode

The blue light will turn on indicate power booster module 3 are in working mode

### Step 2: Button Mode

Situation : When necessary to communicate with another teammate, push the button according to colour assigned

Green button on module 1
pressed, green light on 1 module 2 light up

Yellow button on
module 1 pressed,

yellow light on 2 module 2 light up

Red button on module 1
pressed, red light on 3 module 2 light up

## 7.4 Result Showcase

In our demonstration video, we carried out some testing and verification:

- Tested switching in active-low with internal pull-up configuration
- Verified LED logic (in active-low configuration)
- Sent and received predefined signals between the two nodes
- Confirmed successful transceive capability and bidirectional communication
- Verified that communication was achieved without the aid of cellular networks or

internet

- Verified nodes’ P2P decentralised mesh communication capability

Follow the link to see the demonstration video: https://youtu.be/UirkyzqIXWE

## 8.0 Future works

Challenges
- The current setup only demonstrated direct communication between two nodes
- The repeater feature of the peer-to-peer mesh (Node 3 as a relay) was not fully utilised

in this version

- Given the short range of the nRF24L01+ modules, the system may face limited operational

distance in larger or more complex terrains

- The demonstration focused only on using LEDs to show communication status. However,

the hardware can support much more, it is capable of any signal processing task, unlike

traditional walkie-talkies that only transmit audio

- Security issue due to absence of encryption among the intermediate node’s communication

Improvements
- Implement a third node to fully demonstrate and test the repeater functionality for

extending the network range

- For larger-scale or long-distance communication, consider using alternative radio

technologies such as LoRa to achieve better range and scalability

- Expand the user interface by integrating a graphical OLED panel or even a computer

device, allowing the system to display messages and other data beyond simple LEDs,

implement a feature-rich device that support SMS, document transfers

- Develop a waterproof enclosure for the node to ensure it can operate reliably in harsh

outdoor conditions, especially in rainy or humid environments

- Implement AES-256 encryption for transmitted signals to enhance privacy and security,

ensuring that only authorised devices can read or process the messages, prevent intermediate

nodes from intercepting the message

## 9.0 Conclusion

Our project focused on two primary objectives:

- Exposing students to peer-to-peer (P2P) mesh communication
- Providing hands-on experience in learning to program a microcontroller under their RBT, Computer Science and Physics syllabus

With the aid of our learning kit, students can gain foundational knowledges in assembling hardware, developing firmware and implementing wireless communication between devices. This hands-on approach equips them with a deeper understanding of embedded systems, encourages problem-solving skills, synchronise with their Computer Science and Physics syllabus and benefits for further exploration in the fields of electronics and communication engineering as well.

As time evolve, P2P Decentralised Mesh Communication Technology with RF wireless communication protocol has become a rising technology that increasingly come into our sight. It remains a great potential in the domestic sectors, which currently only being implemented among professional and industry usages, such as military and agriculture. Thus, a domestic market of among this technology is still waited to be explored and excavated. For more details, see [20], [21], [22], [23], [24].

In short, we hope more students get exposed to this technology and head the grounds up, build and construct a P2P Mesh Communication node on their own with provided manuals. As STEM workers are highly in demand these days, we sincerely hope students who get accessed to this kit getting inspired and start contributing their efforts and research on this P2P Mesh Communication Topic to enhance networking technology.

Last but not least, we are driven to deliver the very best in our P2P Mesh Communication Learning Kit to capture the true essence of an educational kit.

## 10.0 References

[1] goTenna. “goTenna and Everywhere Communications Form Strategic Partnership Transforming Enhanced Connectivity,” goTenna Newsroom. Accessed: May 28, 2025. [Online]. Available: https://gotenna.com/blogs/newsroom/gotenna-and-everywhere-communications-form-strategic-partnership-transforming-enhanced-connectivity. (https://gotenna.com/blogs/newsroom/gotenna-and-everywhere-communications-form-strategic-partnership-transforming-enhanced-connectivity)
[2] LoRa Alliance. “LoRaWAN for Smart Agriculture,” LoRa Alliance Video. (Aug 11, 2023). Accessed: May 29, 2025. [Online Video]. Available: https://youtu.be/l2m9ZJIEZ0g?si=08_inty-NZJ2JIVr. (https://youtu.be/l2m9ZJIEZ0g?si=08_inty-NZJ2JIVr)
[3] LoRa Alliance. “LoRaWAN® for Smart Industry,” LoRa Alliance Industry Vertical Market. Accessed: May 29, 2025. [Online]. Available: https://lora-alliance.org/industry-vertical-market/.
[4] Zenarmor. “Mesh Topology: Definition, Practices and Importance,” Zenarmor Docs. Accessed: Jun. 1, 2025. [Online]. Available: https://www.zenarmor.com/docs/network-basics/what-is-mesh-topology. (https://www.zenarmor.com/docs/network-basics/what-is-mesh-topology)
[5] BBC Bitesize. “Computer Networks and Topologies – Mesh networks,” BBC Bitesize. Accessed: Jun. 1, 2025. [Online]. Available: https://www.bbc.co.uk/bitesize/guides/z7mxh39/revision/6.
[6] YouTube. “What is Zigbee and How it Works | Zigbee Network Explained,” (May 22, 2021).
Accessed: Jun. 2, 2025. [Online Video]. Available: https://youtu.be/pFDkibWy0yg?si=w_VuCWbKM7w4yXwP.
[7] CDEBYTE. “News,” CDEBYTE. Accessed: Jun. 2, 2025. [Online]. Available: https://www.cdebyte.com/news/587.
[8] Wikipedia. “Bluetooth Mesh Networking,” Wikipedia. Accessed: Jun. 3, 2025. [Online]. Available: https://en.wikipedia.org/wiki/Bluetooth_mesh_networking.
[9] HowToMechatronics. “Arduino Wireless Communication with NRF24L01 Tutorial,” HowToMechatronics. Accessed: Jun. 5, 2025. [Online]. Available: https://howtomechatronics.com/tutorials/arduino/arduino-wireless-communication-nrf24l01-tutorial/. (https://howtomechatronics.com/tutorials/arduino/arduino-wireless-communication-nrf24l01-tutorial/)
[10] ResearchGate. “Multi-hop cellular network and P2P mobile mesh network,” ResearchGate. Accessed: Jun. 7, 2025. [Online]. Available: https://www.researchgate.net/figure/Multi-hop-cellular-network-and-P2P-mobile-mesh-network_fig1_46476397. (https://www.researchgate.net/figure/Multi-hop-cellular-network-and-P2P-mobile-mesh-network_fig1_46476397)
[11] GeeksforGeeks. “Introduction of Mobile Ad-hoc Network (MANET),” GeeksforGeeks. Accessed: Jun. 7, 2025. [Online]. Available: https://www.geeksforgeeks.org/computer-networks/introduction-of-mobile-ad-hoc-network-manet/. (https://www.geeksforgeeks.org/computer-networks/introduction-of-mobile-ad-hoc-network-manet/)
[12] TechTarget. “Definition of Mesh Network Topology,” IoT Agenda. Accessed: Jun. 10, 2025. [Online]. Available: https://www.techtarget.com/iotagenda/definition/mesh-network-topology-mesh-network. (https://www.techtarget.com/iotagenda/definition/mesh-network-topology-mesh-network)

[13] Arduino Store. “Arduino Nano,” Arduino Official Store. Accessed: Jun. 14, 2025. [Online]. Available: https://store.arduino.cc/products/arduino-nano.
[14] NRF24 Library Docs. “RF24 Class Reference,” NRF24 GitHub Pages. Accessed: Jun. 15, 2025. [Online]. Available: https://nrf24.github.io/RF24/classRF24.html.
[15] Cytron Technologies. “Wireless NRF24L01 Plus PA/LNA with Antenna,” Cytron. Accessed: Jun. 15, 2025. [Online]. Available: https://my.cytron.io/p-wireless-nrf24l01-plus-pa-lna-with-antenna. (https://my.cytron.io/p-wireless-nrf24l01-plus-pa-lna-with-antenna)
[16] SparkFun. “nRF24L01+ Product Specification,” SparkFun. Accessed: Jun. 17, 2025. [Online]. Available: https://cdn.sparkfun.com/assets/3/d/8/5/1/nRF24L01P_Product_Specification_1_0.pdf.
[17] Last Minute Engineers. “nRF24L01+ Arduino Wireless Communication,” Last Minute Engineers. Accessed: Jun. 18, 2025. [Online]. Available: https://lastminuteengineers.com/nrf24l01-arduino-wireless-communication/. (https://lastminuteengineers.com/nrf24l01-arduino-wireless-communication/)
[18] Circuits-DIY. “Pull-up and Pull-down Resistor Electronics Tutorial,” Circuits-DIY. Accessed: Jun. 22, 2025. [Online]. Available: https://www.circuits-diy.com/pull-up-and-pull-down-resistor-electronics-tutorial/. (https://www.circuits-diy.com/pull-up-and-pull-down-resistor-electronics-tutorial/)
[19] Flowcode. “Component: LED Array Template,” Flowcode Wiki. Accessed: Jun. 22, 2025. [Online]. Available:
https://www.flowcode.co.uk/wiki_old/wikiv8/index.php?title=Component:_LED_Array_Template_(Outputs:_LEDs). (https://www.flowcode.co.uk/wiki_old/wikiv8/index.php)
[20] Chai, Y., Zeng, X.-J., & Liu, Z. “The future of wireless mesh network in next-generation communication: a perspective overview,” Evolving Systems, Apr. 28, 2025 (e-pub ahead of print, Aug. 2024). Accessed: Jun. 24, 2025. [Online]. Available: https://www.researchgate.net/publication/380031685_The_future_of_wireless_mesh_network_in_next-generation_communication_a_perspective_overview (https://www.researchgate.net/publication/380031685_The_future_of_wireless_mesh_network_in_next-generation_communication_a_perspective_overview)
[21] Berto, R.; Napoletano, P.; Savi, M. “A LoRa-Based Mesh Network for Peer-to-Peer Long-Range Communication,” Sensors, vol. 21, no. 13, p. 4314, Jun. 24 2021. Accessed: Jun. 24, 2025. [Online]. Available: https://doi.org/10.3390/s21134314
[22] Roots Analysis. “Wireless Mesh Network Market, Till 2035,” Roots Analysis, published recently. Accessed: Jun. 24, 2025. [Online]. Available: https://www.rootsanalysis.com/wireless-mesh-network-market (https://www.rootsanalysis.com/wireless-mesh-network-market)
[23] MDPI. “Performance Evaluation of a Mesh-Topology LoRa Network,” May 2025. Accessed: Jun. 24, 2025. [Online]. Available: https://www.mdpi.com/1424-8220/25/5/1602
[24] Wikipedia. “Meshtastic,” updated Jun. 2025. Accessed: Jun. 24, 2025. [Online]. Available: https://en.wikipedia.org/wiki/Meshtastic

## 11.0 Appendix

KSSM Form 4 Physics — Relevance to Types of Waves

KSSM Form 2 Reka Bentuk dan Teknologi — Relevance to Microcontroller Usage

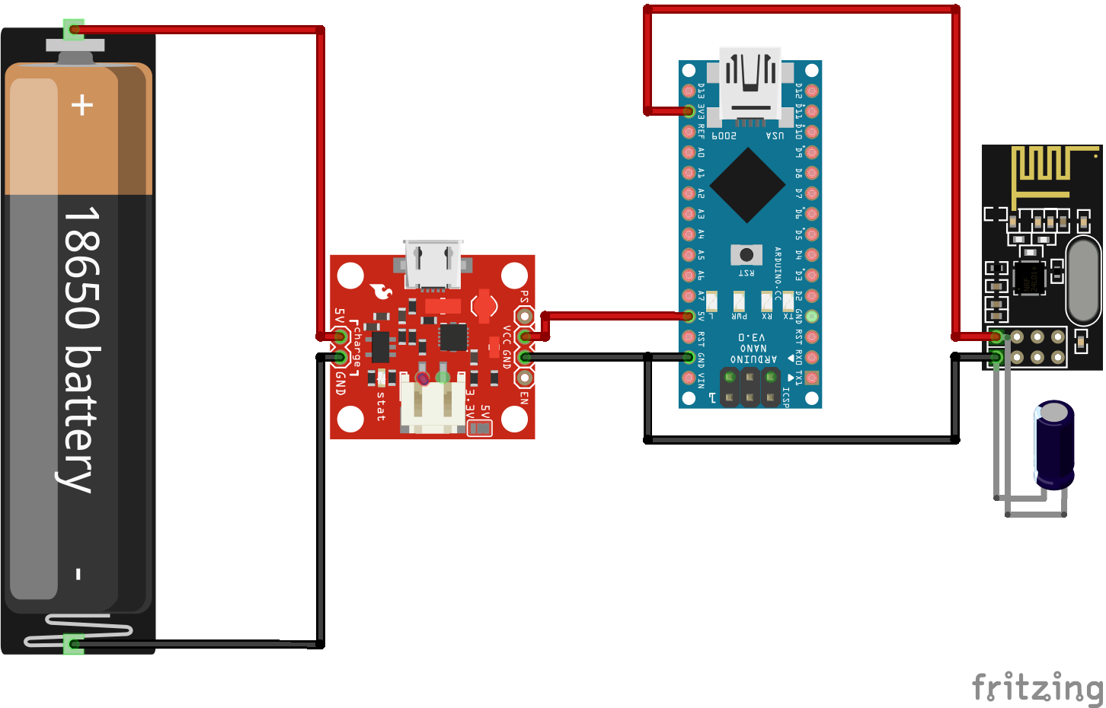
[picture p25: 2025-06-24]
fritzingSchematics/powerSupplyDemo_bb.png

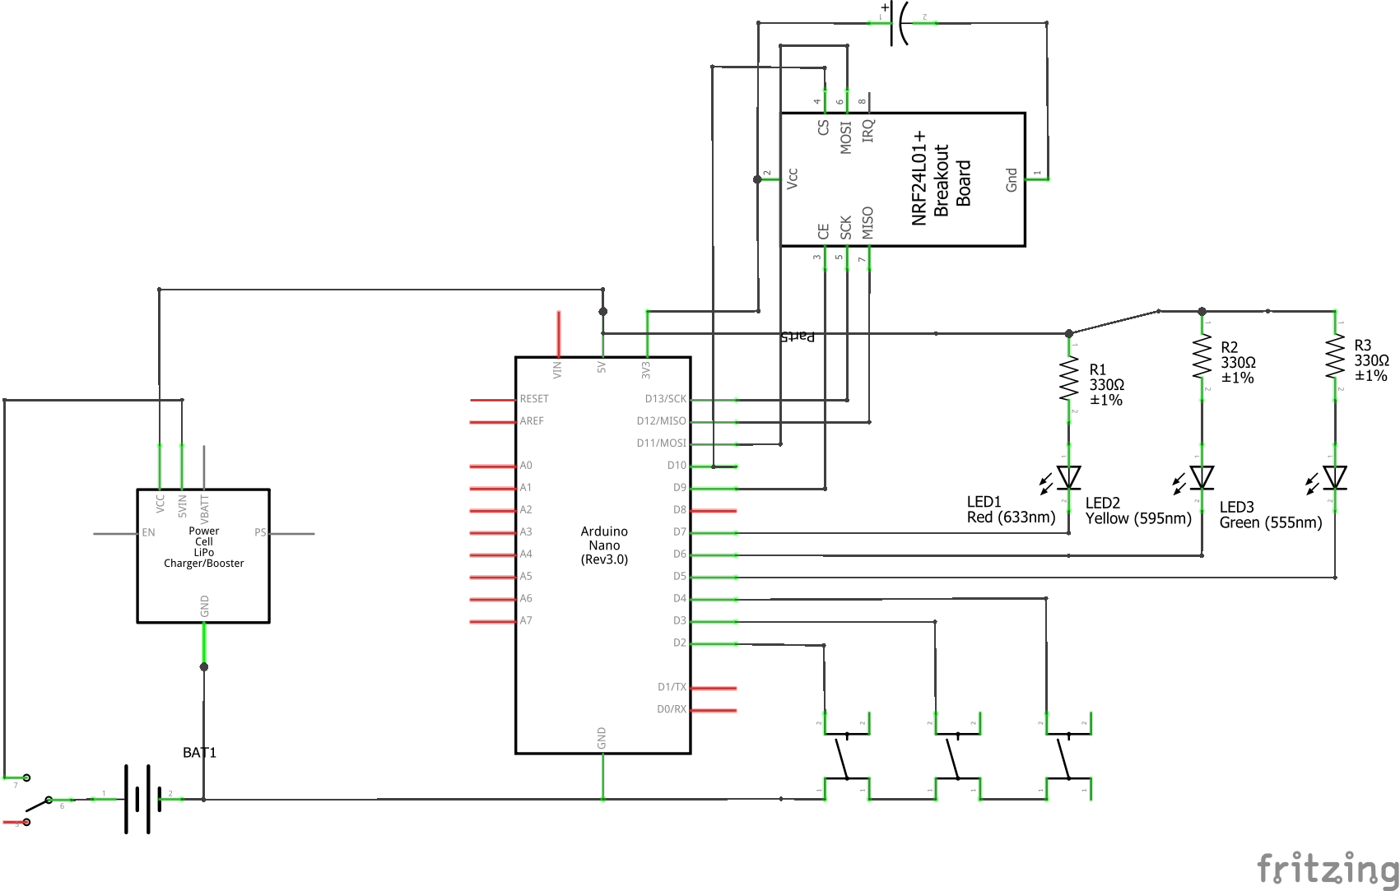
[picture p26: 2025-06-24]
fritzingSchematics/P2Platest_schem.png

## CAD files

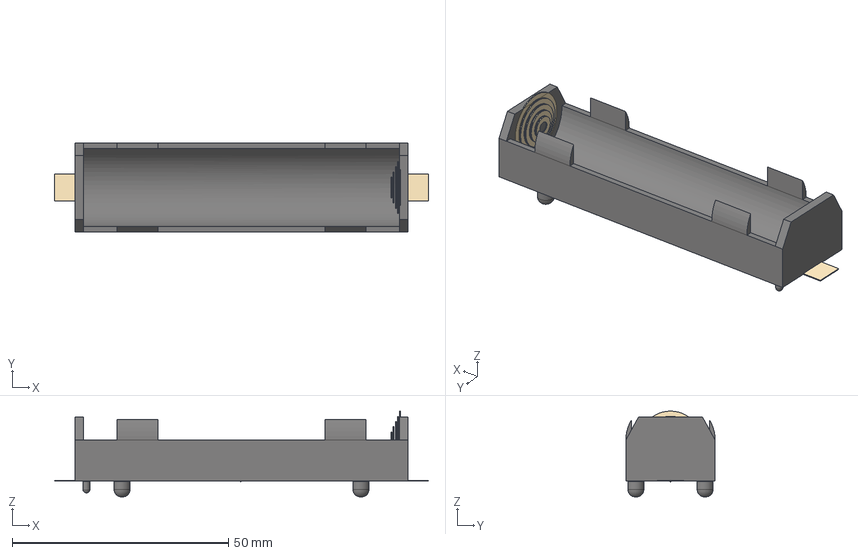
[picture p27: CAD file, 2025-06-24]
kicadModels/P2PNode_SMD/3dmodels/batteryHolder/BatteryHolder_Keystone_1042_1x18650.step
86.4 x 20.6 x 19.8 mm

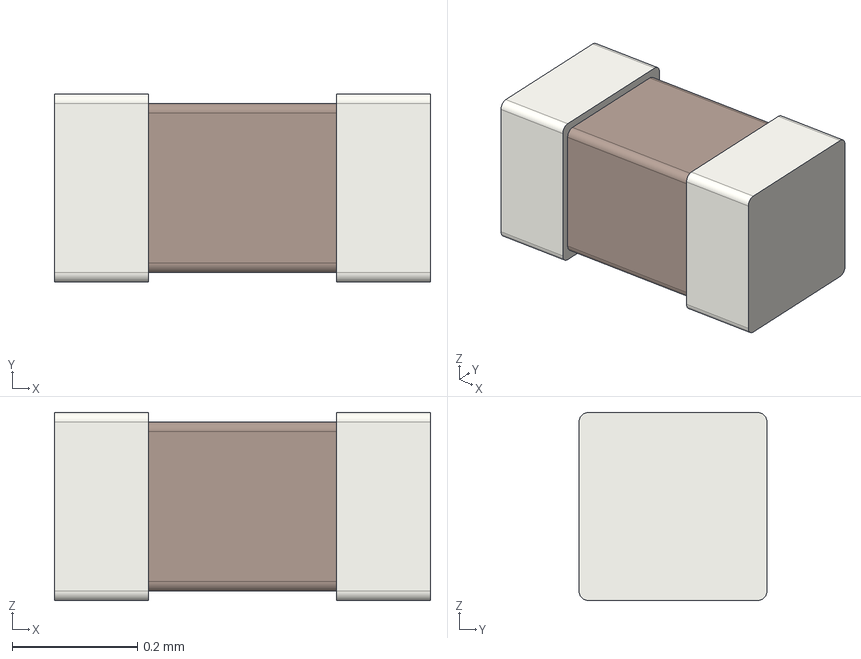
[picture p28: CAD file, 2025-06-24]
kicadModels/P2PNode_SMD/3dmodels/capacitorSMD/C_0201_0603Metric.step
0.6 x 0.3 x 0.3 mm

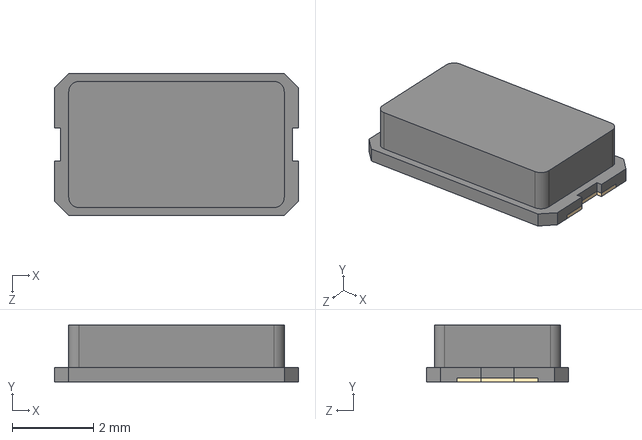
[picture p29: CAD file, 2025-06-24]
kicadModels/P2PNode_SMD/3dmodels/crystalAbracon/Crystal_SMD_Abracon_ABM7-2Pin_6.0x3.5mm.step
6.00 x 1.40 x 3.50 mm

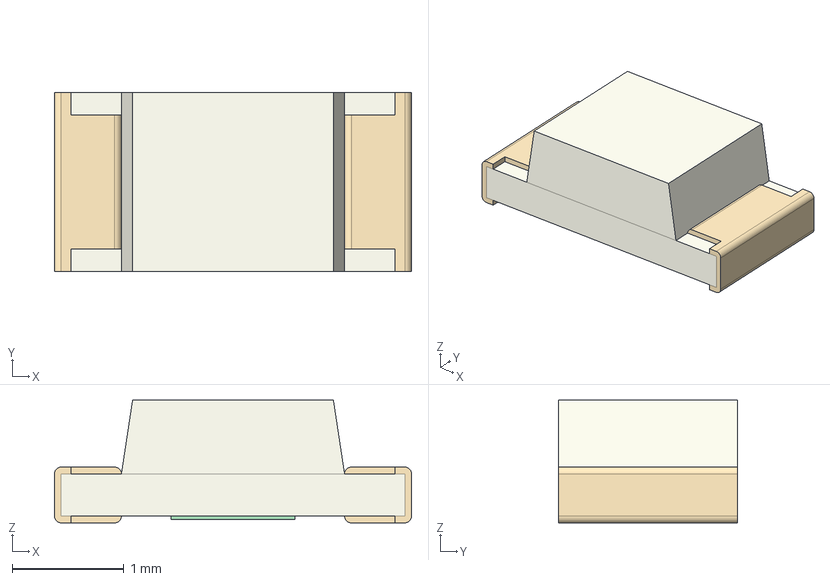
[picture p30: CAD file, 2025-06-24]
kicadModels/P2PNode_SMD/3dmodels/ledSMD/LED_1206_3216Metric.step
3.20 x 1.60 x 1.10 mm

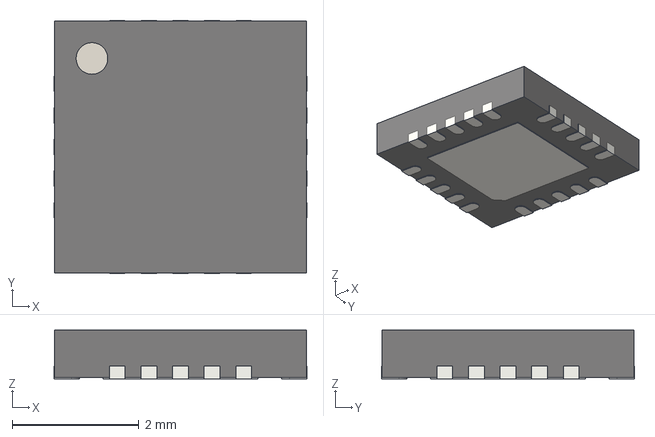
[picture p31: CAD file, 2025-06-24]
kicadModels/P2PNode_SMD/3dmodels/nrfModule/QFN-20-1EP_4x4mm_P0.5mm_EP2.5x2.5mm.step
4.00 x 4.00 x 0.77 mm

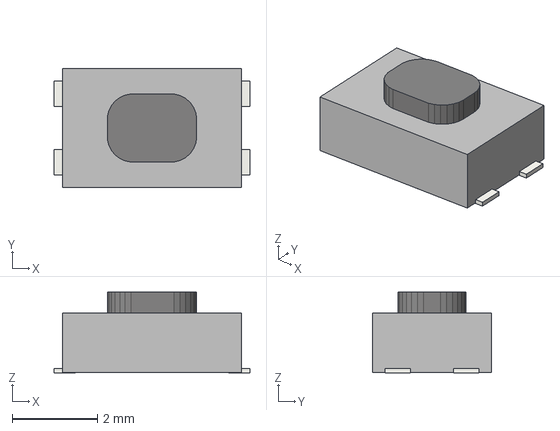
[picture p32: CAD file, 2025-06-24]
kicadModels/P2PNode_SMD/3dmodels/pushButton/SW_Push_1P1T_NO_CK_KMR2.step
4.60 x 2.80 x 1.90 mm

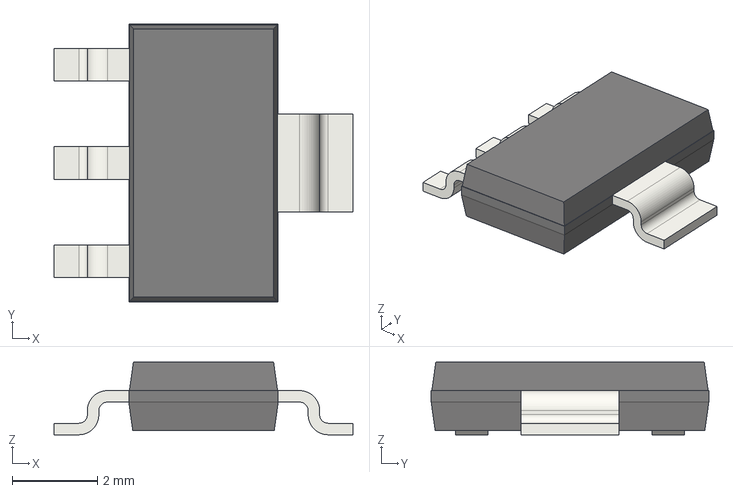
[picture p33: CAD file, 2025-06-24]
kicadModels/P2PNode_SMD/3dmodels/regulatorAMS1117/SOT-223.step
7.00 x 6.50 x 1.70 mm

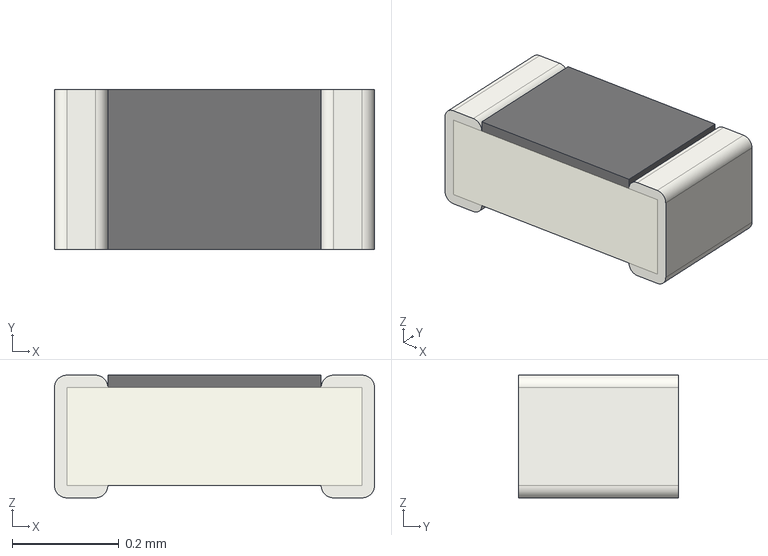
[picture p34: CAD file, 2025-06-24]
kicadModels/P2PNode_SMD/3dmodels/resistorSMD/R_0201_0603Metric.step
0.6 x 0.3 x 0.23 mm

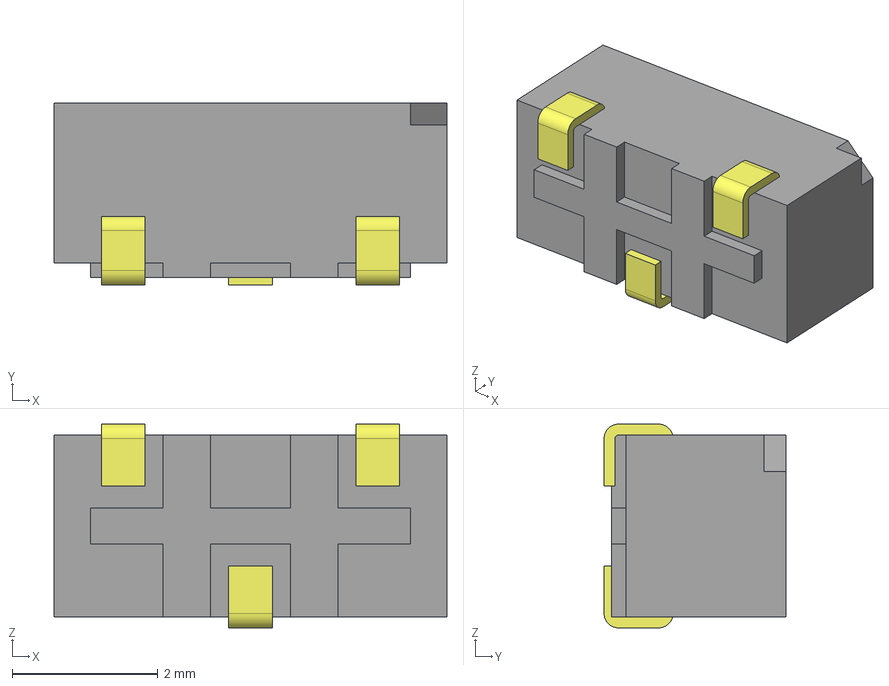
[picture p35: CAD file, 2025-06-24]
kicadModels/P2PNode_SMD/3dmodels/switchSMD/Nidec_Copal_CAS-120A.step
5.40 x 2.50 x 2.80 mm
CAS_c_12A
1 pole_s

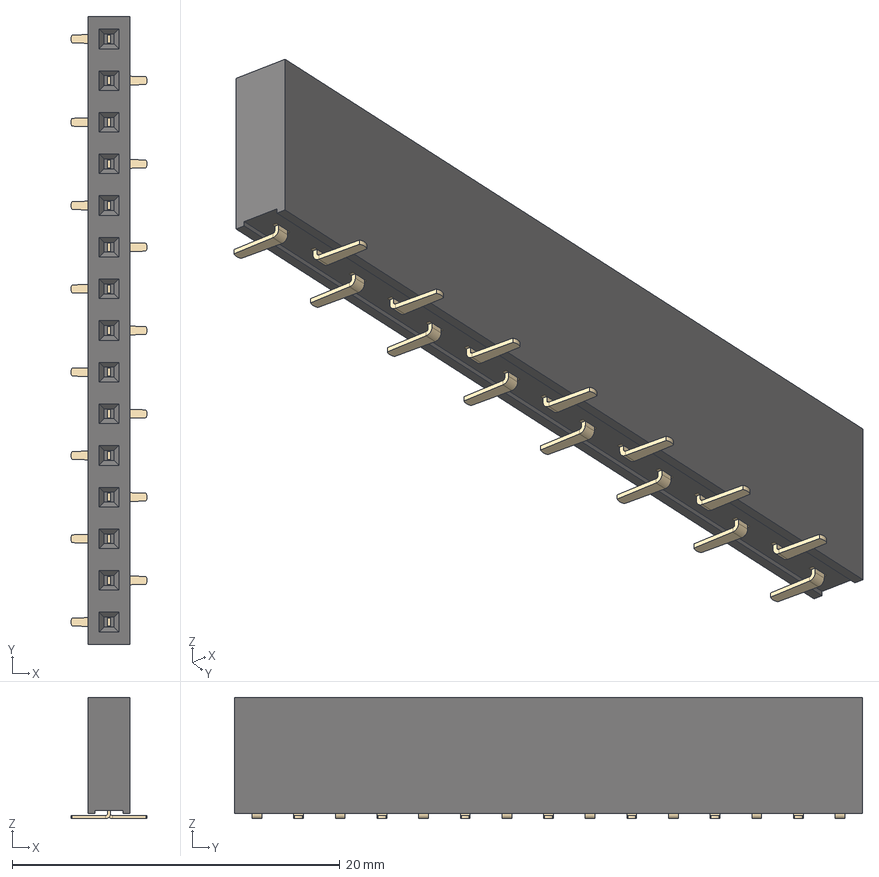
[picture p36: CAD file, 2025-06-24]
kicadModels/P2PNode_THT/3dmodels/arduinoNano/pinLeft.step
4.64 x 38.3 x 7.40 mm

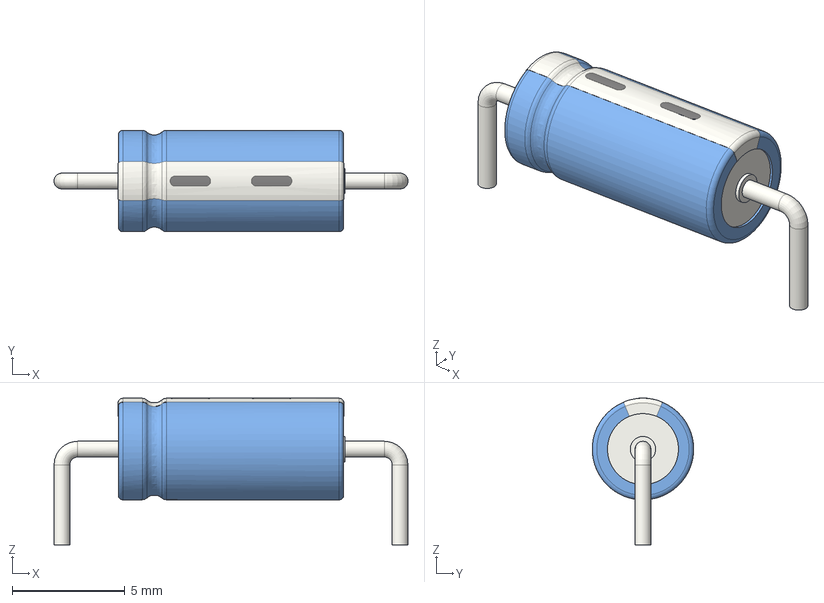
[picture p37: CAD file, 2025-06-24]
kicadModels/P2PNode_THT/3dmodels/capacitor/CP_Axial_L10.0mm_D4.5mm_P15.00mm_Horizontal.step
15.7 x 4.50 x 6.51 mm

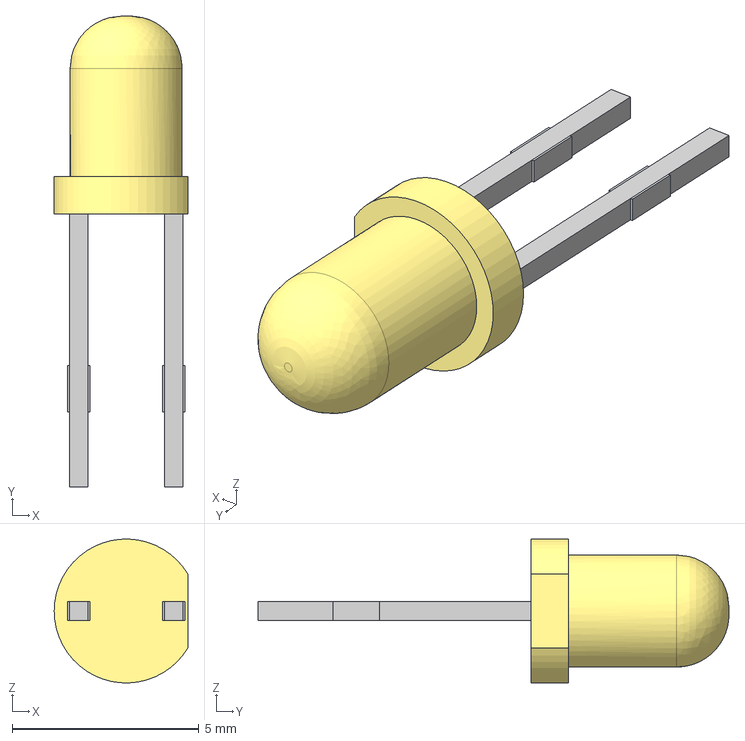
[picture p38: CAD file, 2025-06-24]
kicadModels/P2PNode_THT/3dmodels/leds/LED_3mm_Yellow.step
3.58 x 12.6 x 3.85 mm

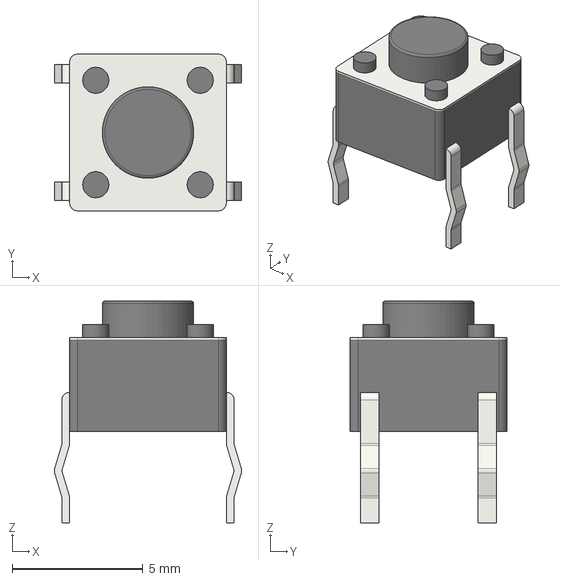
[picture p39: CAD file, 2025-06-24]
kicadModels/P2PNode_THT/3dmodels/pushButton/SW_PUSH_6mm_H5mm.step
7.17 x 6.00 x 8.50 mm

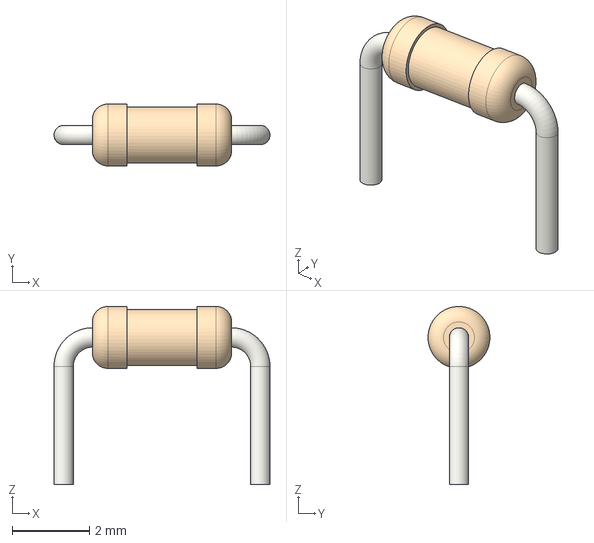
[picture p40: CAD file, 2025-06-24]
kicadModels/P2PNode_THT/3dmodels/resistor/R_Axial_DIN0204_L3.6mm_D1.6mm_P5.08mm_Horizontal.step
5.58 x 1.60 x 4.60 mm

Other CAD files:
kicadModels/P2PNode_THT/3dmodels/arduinoNano/pinRight.step
kicadModels/P2PNode_SMD/3dmodels/battery18650/18650.step
kicadModels/P2PNode_THT/3dmodels/leds/LED_3mm_Green.step
kicadModels/P2PNode_THT/3dmodels/leds/LED_3mm_Red.step

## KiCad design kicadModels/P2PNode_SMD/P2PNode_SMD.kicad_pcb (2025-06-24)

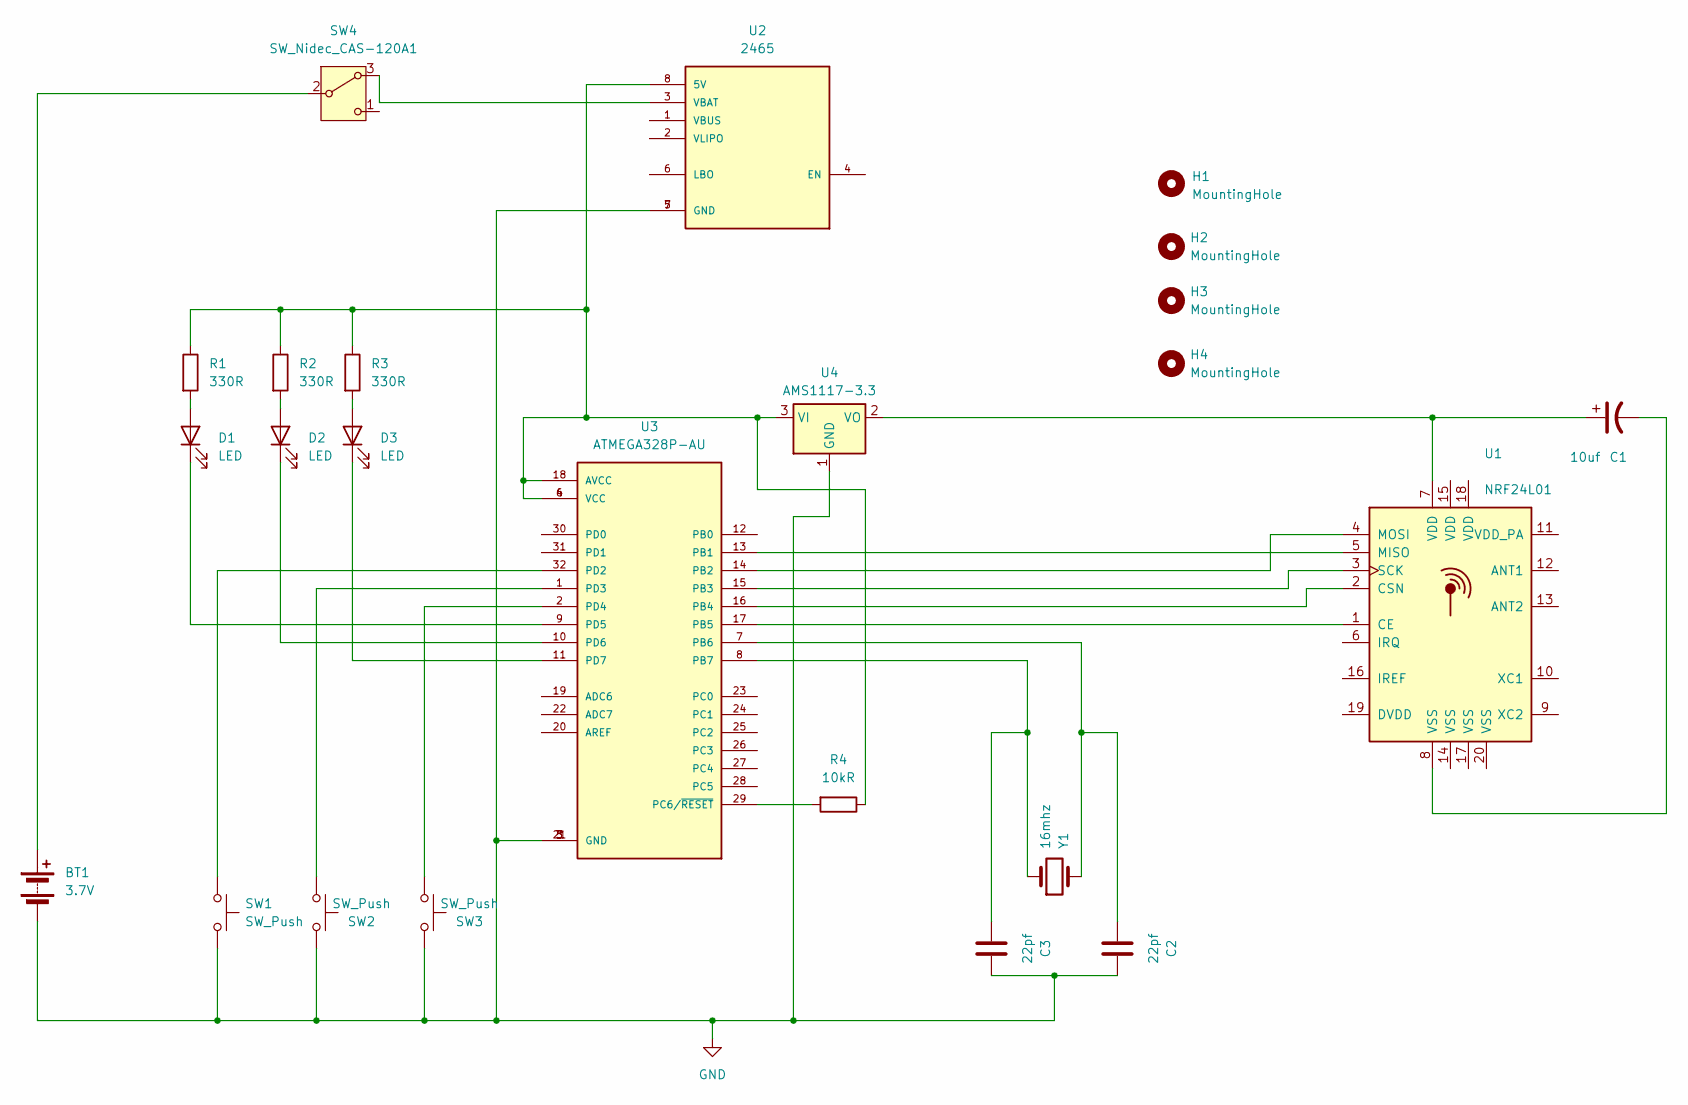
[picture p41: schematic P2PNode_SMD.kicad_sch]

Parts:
BT1: 3.7V; BatteryHolder_Keystone_1042_1x18650
C1: 10uf; C_0201_0603Metric
C2, C3: 22pf; C_0201_0603Metric
D1, D2, D3: LED; LED_1206_3216Metric
H1, H2, H3, H4: MountingHole; MountingHole_2.1mm
R1, R2, R3: 330R; R_0201_0603Metric
R4: 10kR; R_0201_0603Metric
SW1, SW2, SW3: SW_Push; SW_Push_1P1T_NO_CK_KMR2
SW4: SW_Nidec_CAS-120A1; Nidec_Copal_CAS-120A
U1: NRF24L01; QFN-20-1EP_4x4mm_P0.5mm_EP2.5x2.5mm
U2: 2465; MODULE_2465; PARTREV B
U3: ATMEGA328P-AU; QFP80P900X900X120-32N; PARTREV 8271A
U4: AMS1117-3.3; SOT-223-3_TabPin2
Y1: 16mhz; Crystal_SMD_Abracon_ABM7-2Pin_6.0x3.5mm

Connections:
GND: BT1.2 (-), C2.2, C3.2, SW1.2, SW2.2, SW3.2, U2.5 (GND), U2.7 (GND), U3.3 (GND), U3.5 (GND), U3.21 (GND), U4.1 (GND)
unnamed: BT1.1 (+), SW4.2 (B)
unnamed: C1.2, U1.8 (VSS)
unnamed: D1.2 (A), R1.2
unnamed: D1.1 (K), U3.9 (PD5)
unnamed: D2.2 (A), R2.2
unnamed: D2.1 (K), U3.10 (PD6)
unnamed: D3.2 (A), R3.2
unnamed: D3.1 (K), U3.11 (PD7)
unnamed: SW4.3 (A), U2.3 (VBAT)
unnamed: U1.1 (CE), U3.17 (PB5)
unnamed: U1.2 (CSN), U3.16 (PB4)
unnamed: U1.5 (MISO), U3.13 (PB1)
unnamed: U1.4 (MOSI), U3.14 (PB2)
unnamed: U1.3 (SCK), U3.15 (PB3)
unnamed: R1.1, R2.1, R3.1, R4.1, U2.8 (5V), U3.4 (VCC), U3.6 (VCC), U3.18 (AVCC), U4.3 (VI)
unnamed: C2.1, U3.7 (PB6), Y1.2
unnamed: C3.1, U3.8 (PB7), Y1.1
unnamed: R4.2, U3.29 (PC6/~RESET)
unnamed: SW1.1, U3.32 (PD2)
unnamed: SW2.1, U3.1 (PD3)
unnamed: SW3.1, U3.2 (PD4)
unnamed: C1.1, U1.7 (VDD), U4.2 (VO)

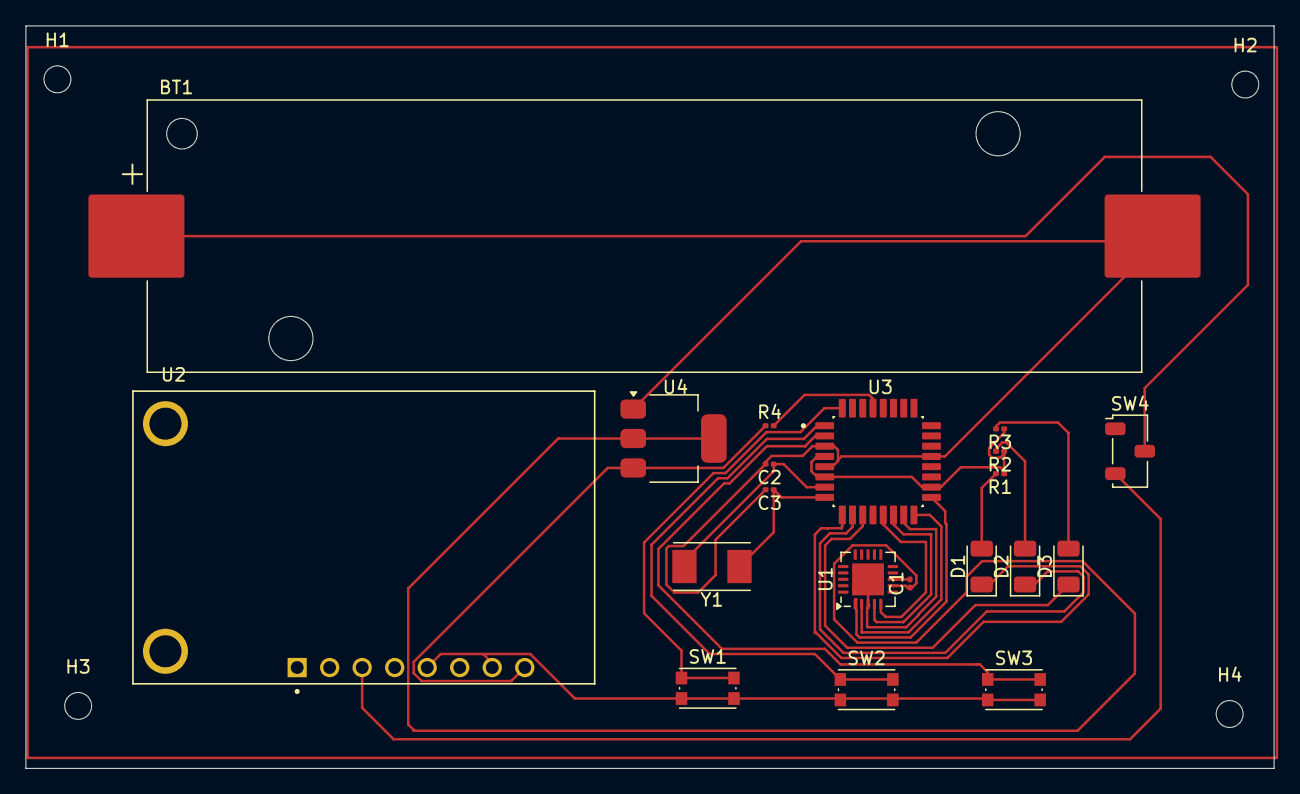
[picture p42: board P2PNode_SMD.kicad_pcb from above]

Board: 2 copper layers, 97.5 x 58.0 mm, 24 parts (0 on the bottom side), 23 nets.

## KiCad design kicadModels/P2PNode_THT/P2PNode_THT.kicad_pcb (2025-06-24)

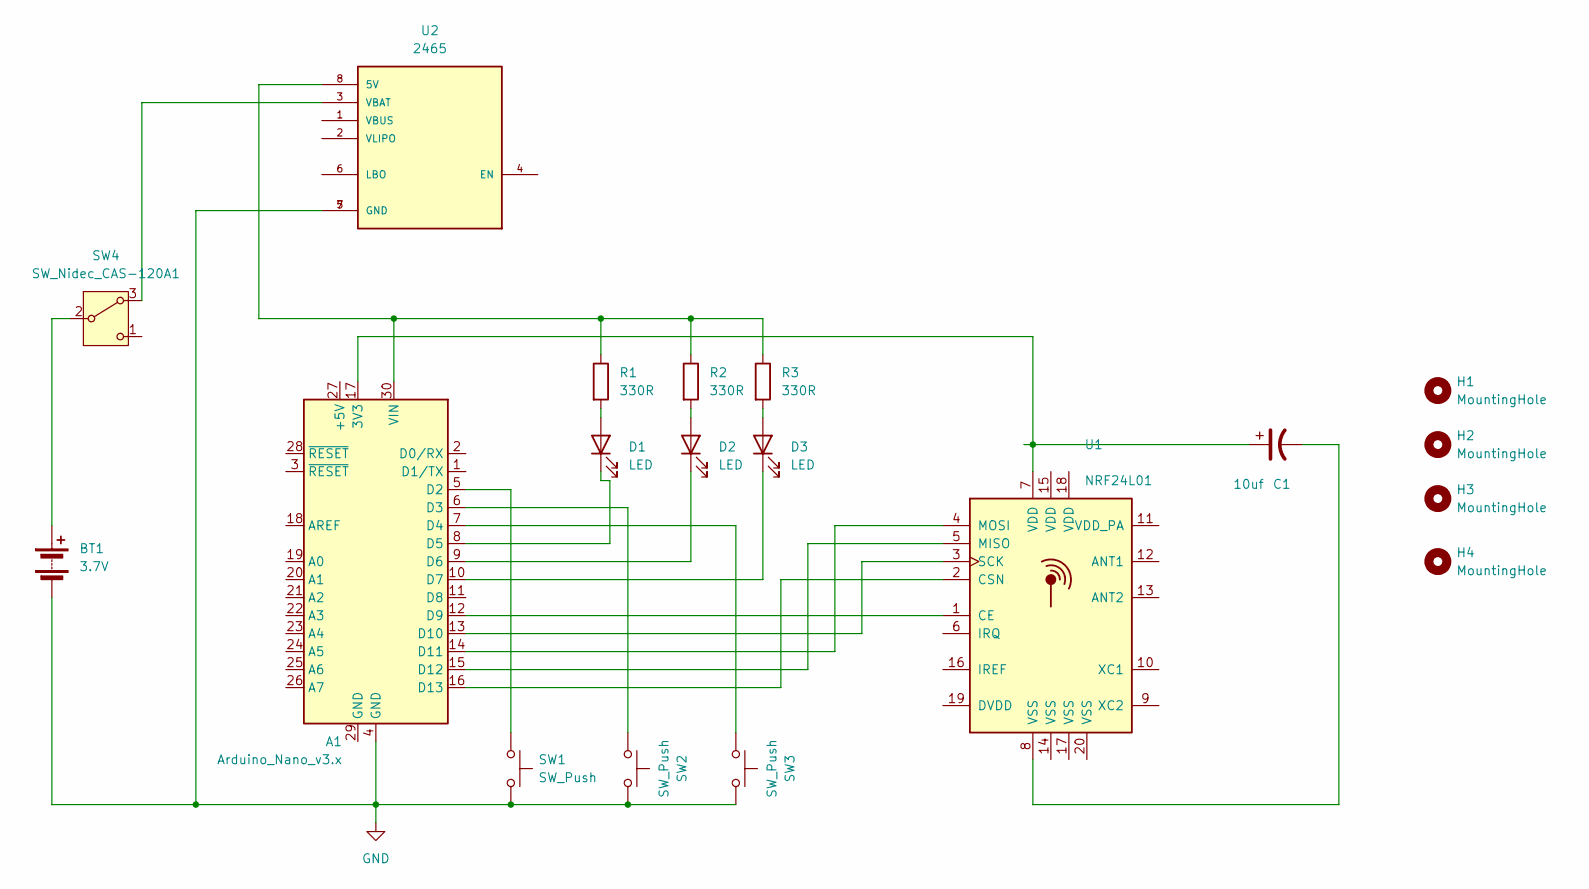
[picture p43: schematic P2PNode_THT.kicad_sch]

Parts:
A1: Arduino_Nano_v3.x; Arduino_Nano
BT1: 3.7V; BatteryHolder_Keystone_1042_1x18650
C1: 10uf; CP_Axial_L10.0mm_D4.5mm_P15.00mm_Horizontal
D1, D2, D3: LED; LED_D3.0mm
H1, H2, H3, H4: MountingHole; MountingHole_2.1mm
R1, R2, R3: 330R; R_Axial_DIN0204_L3.6mm_D1.6mm_P5.08mm_Horizontal
SW1, SW2, SW3: SW_Push; SW_PUSH_6mm_H5mm
SW4: SW_Nidec_CAS-120A1; Nidec_Copal_CAS-120A
U1: NRF24L01; QFN-20-1EP_4x4mm_P0.5mm_EP2.5x2.5mm
U2: 2465; MODULE_2465; PARTREV B

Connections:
GND: A1.4 (GND), BT1.2 (-), SW1.2, SW2.2, SW3.2, U2.5 (GND), U2.7 (GND)
unnamed: A1.17 (3V3), C1.1, U1.7 (VDD)
unnamed: A1.5 (D2), SW1.1
unnamed: A1.6 (D3), SW2.1
unnamed: A1.7 (D4), SW3.1
unnamed: A1.8 (D5), D1.1 (K)
unnamed: A1.9 (D6), D2.1 (K)
unnamed: A1.10 (D7), D3.1 (K)
unnamed: A1.12 (D9), U1.1 (CE)
unnamed: A1.13 (D10), U1.3 (SCK)
unnamed: A1.14 (D11), U1.4 (MOSI)
unnamed: A1.15 (D12), U1.5 (MISO)
unnamed: A1.16 (D13), U1.2 (CSN)
unnamed: A1.30 (VIN), R1.1, R2.1, R3.1, U2.8 (5V)
unnamed: BT1.1 (+), SW4.2 (B)
unnamed: C1.2, U1.8 (VSS)
unnamed: D1.2 (A), R1.2
unnamed: D2.2 (A), R2.2
unnamed: D3.2 (A), R3.2
unnamed: SW4.3 (A), U2.3 (VBAT)

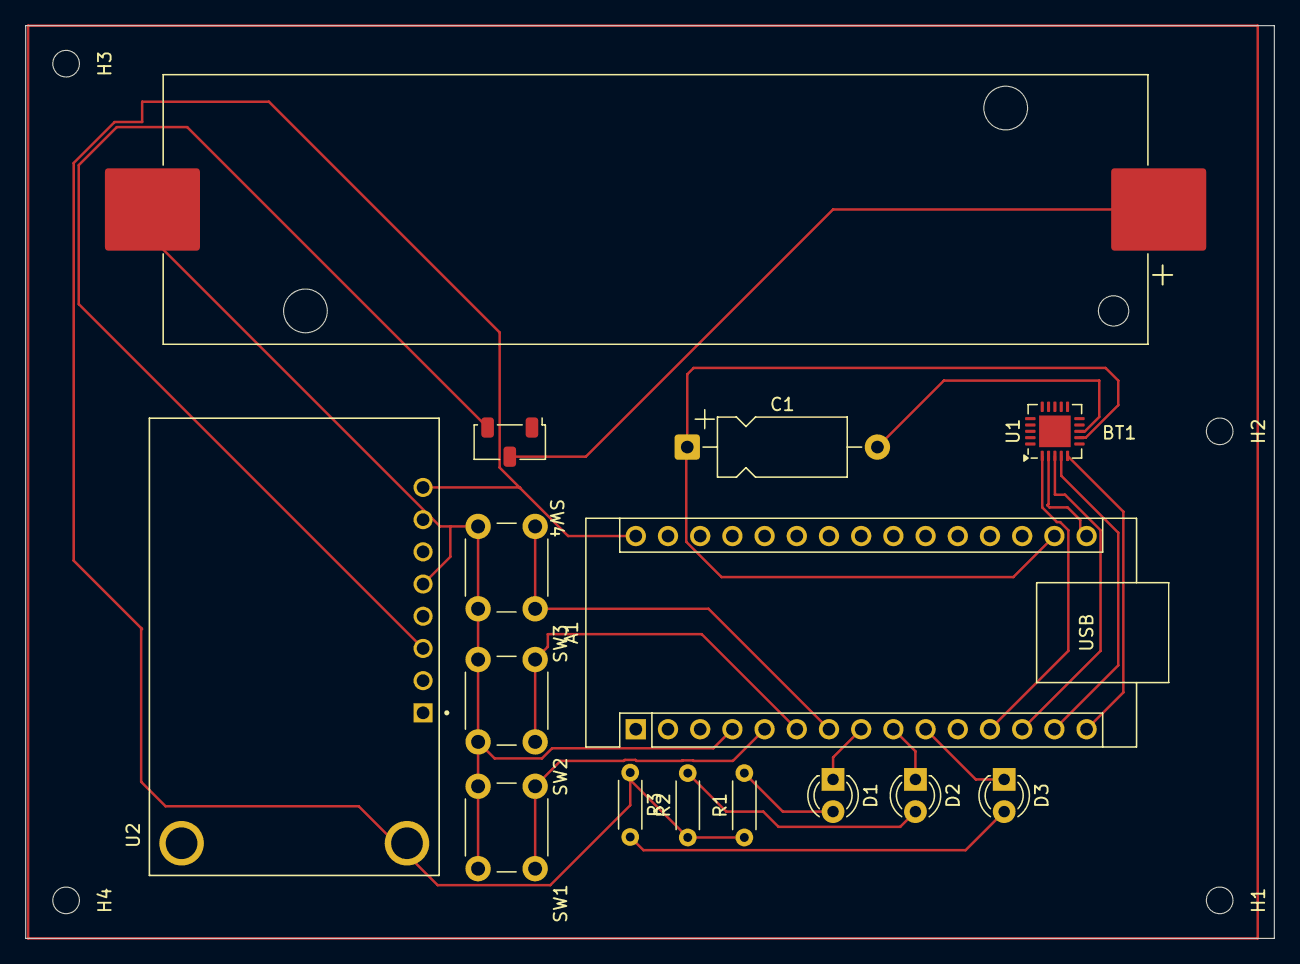
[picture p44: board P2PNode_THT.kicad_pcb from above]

Board: 2 copper layers, 98.5 x 72.0 mm, 19 parts (0 on the bottom side), 20 nets.

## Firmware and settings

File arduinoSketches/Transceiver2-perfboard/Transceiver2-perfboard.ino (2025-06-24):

#include <SPI.h>
#include <nRF24L01.h>
#include <RF24.h>

#define BTN_GREEN 2
#define BTN_YELLOW 3
#define BTN_RED 4 

#define LED_GREEN 5
#define LED_YELLOW 6
#define LED_RED 7

RF24 radio(9, 10); // CE, CSN

// Update addresses for each node
const byte thisNode[6] = "NODE2";
const byte otherNode[6] = "NODE1";

// Store button and LED states
bool buttonStates[3] = {0, 0, 0};
bool lastButtonStates[3] = {0, 0, 0};
bool ledStates[3] = {0, 0, 0};

void setup() {
  Serial.begin(9600);

  pinMode(BTN_GREEN, INPUT_PULLUP);
  pinMode(BTN_YELLOW, INPUT_PULLUP);
  pinMode(BTN_RED, INPUT_PULLUP);

  pinMode(LED_GREEN, OUTPUT);
  pinMode(LED_YELLOW, OUTPUT);
  pinMode(LED_RED, OUTPUT);

  digitalWrite(LED_GREEN, HIGH);
  digitalWrite(LED_YELLOW, HIGH);
  digitalWrite(LED_RED, HIGH);

  radio.begin();
  radio.openWritingPipe(otherNode);  // Address to send to
  radio.openReadingPipe(1, thisNode); // Address to receive on
  radio.setPALevel(RF24_PA_LOW);
  radio.stopListening();  // Start in transmit mode
}

void loop() {
  // READ BUTTONS
  buttonStates[0] = !digitalRead(BTN_GREEN);  // Active LOW
  buttonStates[1] = !digitalRead(BTN_YELLOW);
  buttonStates[2] = !digitalRead(BTN_RED);

  // IF BUTTON CHANGED → Send
  bool sendNeeded = false;
  for (int i = 0; i < 3; i++) {
    if (buttonStates[i] != lastButtonStates[i]) {
      sendNeeded = true;
      lastButtonStates[i] = buttonStates[i];
    }
  }

  if (sendNeeded) {
    radio.stopListening();  // Switch to TX mode
    radio.write(&buttonStates, sizeof(buttonStates));
  }

  // RECEIVE if data available
  radio.startListening();
  unsigned long startTime = millis();
  while (!radio.available()) {
    if (millis() - startTime > 5) break;  // Non-blocking wait
  }

  if (radio.available()) {
    radio.read(&ledStates, sizeof(ledStates));
    digitalWrite(LED_GREEN, !ledStates[0]);
    digitalWrite(LED_YELLOW, !ledStates[1]);
    digitalWrite(LED_RED, !ledStates[2]);
  }

  delay(10);  // Small delay to avoid flooding
}

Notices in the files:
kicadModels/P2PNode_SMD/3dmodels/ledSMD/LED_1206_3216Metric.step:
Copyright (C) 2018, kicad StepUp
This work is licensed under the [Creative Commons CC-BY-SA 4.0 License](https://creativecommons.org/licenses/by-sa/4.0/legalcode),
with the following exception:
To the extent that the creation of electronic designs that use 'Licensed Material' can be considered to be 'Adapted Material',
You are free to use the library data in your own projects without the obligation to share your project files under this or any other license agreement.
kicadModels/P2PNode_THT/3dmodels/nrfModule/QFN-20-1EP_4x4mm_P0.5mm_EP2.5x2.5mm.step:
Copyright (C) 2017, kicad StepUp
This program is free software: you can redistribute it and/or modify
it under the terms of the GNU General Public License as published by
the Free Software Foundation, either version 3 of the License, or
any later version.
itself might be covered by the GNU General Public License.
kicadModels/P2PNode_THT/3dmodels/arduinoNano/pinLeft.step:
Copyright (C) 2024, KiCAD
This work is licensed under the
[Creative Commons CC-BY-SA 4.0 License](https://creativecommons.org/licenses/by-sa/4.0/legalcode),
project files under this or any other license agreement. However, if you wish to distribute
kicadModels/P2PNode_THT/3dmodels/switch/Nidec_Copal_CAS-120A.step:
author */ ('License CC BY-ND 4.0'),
